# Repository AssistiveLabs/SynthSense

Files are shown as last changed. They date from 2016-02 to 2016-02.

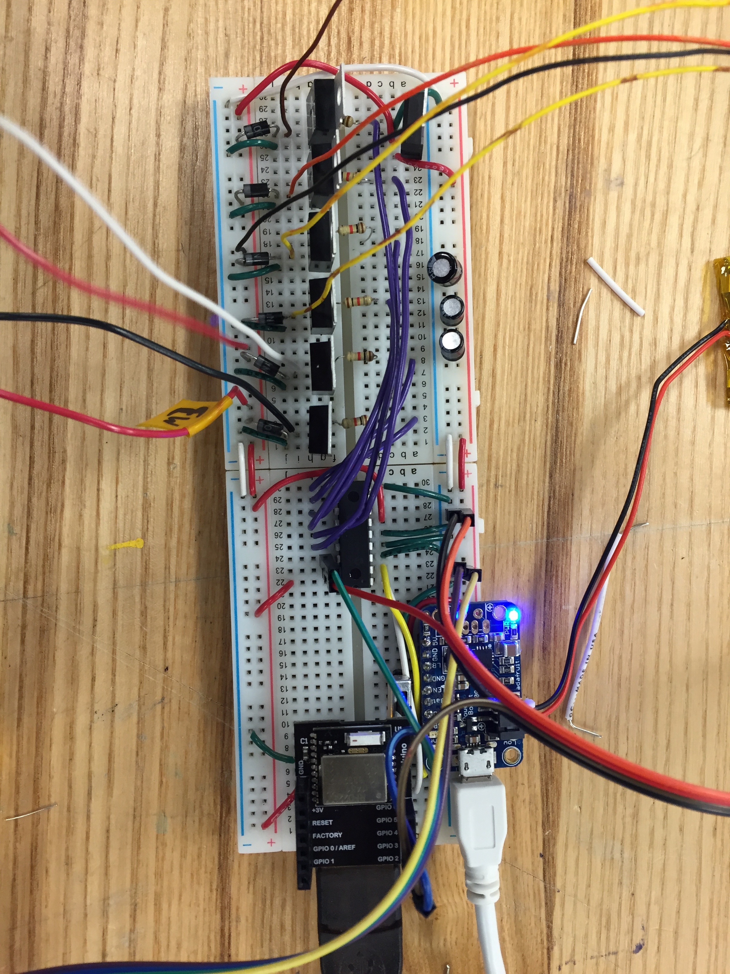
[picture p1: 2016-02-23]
images/Electronics1.jpg

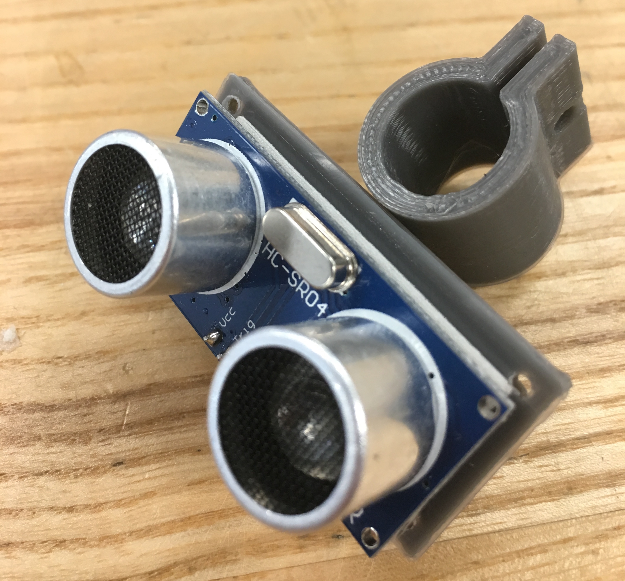
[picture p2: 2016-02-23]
images/Sensor1.JPG

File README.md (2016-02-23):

##SynthSense

####Team
Craig Hiller, Frank Lu, Adithya Murali, Krishna Parashar, Tomás Vega

####Course
Interactive Device Design, fall 2015

Aimed at empowering the visually impaired by augmenting their awareness of the environment and facilitating independence, SynthSense is an open-source Augmented White Cane (AWC) that provides both obstacle avoidance and navigation assistance.

To help with obstacle avoidance, the team built a cane with ultrasonic range finders for detecting obstacles within a two-meter range as well as mounts for the sensors that are both direction- and height-adjustable. Feedback from these sensors deliver haptic responses on the handle when obstacles are detected at body or head level.

To provide navigation instructions to users, the SynthSense team developed an iOS app that determines when the user needs to turn. The app transmits a command to the AWC’s strap, providing directional haptic feedback that the user can act on.

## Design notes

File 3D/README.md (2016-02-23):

# CAD-files
3D models for enclosures and mounts.

### Handle Enclosure
[A360 Link](http://a360.co/1NjnoRl)
Image of finished enclosure

### Sensor Mount and Enclosure
[A360 Link](http://a360.co/1NjnrN0)
Image of finished sensor mount

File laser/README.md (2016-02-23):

# SynthSense Laser Files
The files in this repo are what we used to create the HC-SR04 (ultrasonic ranger) enclosures out of acrylic and the navigation wrist band, which was made out of leather.

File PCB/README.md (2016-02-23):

#SynthSense PCB

---

###Components
- [RFduino](http://www.rfduino.com/wp-content/uploads/2015/08/RFD22301.Data.Sheet.08.20.15_4.36PM.pdf)
- [IO Extender (MCP32008)](http://ww1.microchip.com/downloads/en/DeviceDoc/21919e.pdf)
- [SparkFun Power Cell - LiPo Charger/Booster](https://www.sparkfun.com/products/11231)

###Inputs
- [2x Ultrasonic Range Finder (HC-SR04)](http://www.amazon.com/SainSmart-HC-SR04-Ranging-Detector-Distance/dp/B004U8TOE6)

###Outputs
- [6x 12mm x 3.4mm coin motor](http://www.amazon.com/Voltage-Vibration-Micro-Motor-Phone/dp/B00NP4ARF6/)
  - Voltage: 1.5v-3v
  - Continuous Current: 55mA

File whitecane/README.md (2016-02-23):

## SynthSense
### Obstacle Avoidance

Navigating to a completely unfamiliar surrounding is already difficult, it’s also a challenge to avoid obstacles on the way to a destination. The main issues are

#### Sidewalk Crack Detection
  - Cracks are really hard to notice. An uneven road surface can easily trip anyone. Moreover, canes can get stuck in a crack and break. No current cane system we could find detects this. Our alert system will alert the user before such situations occur. 
#### Overhead Obstacles
  - Low hanging tree branches are hard to detect because the normal assistive device only detects ground level objects. Current systems allow for this. We intend to integrate it into our device.
#### Thin objects
  - Objects such as flag poles  and tree trunks are very easy to miss due to how skinny they are.

#### Possible Solutions
- Augment the white cane
- Delivers feedback on objects above ground-level
- Magnetometer + multiple distance sensors (TBD)

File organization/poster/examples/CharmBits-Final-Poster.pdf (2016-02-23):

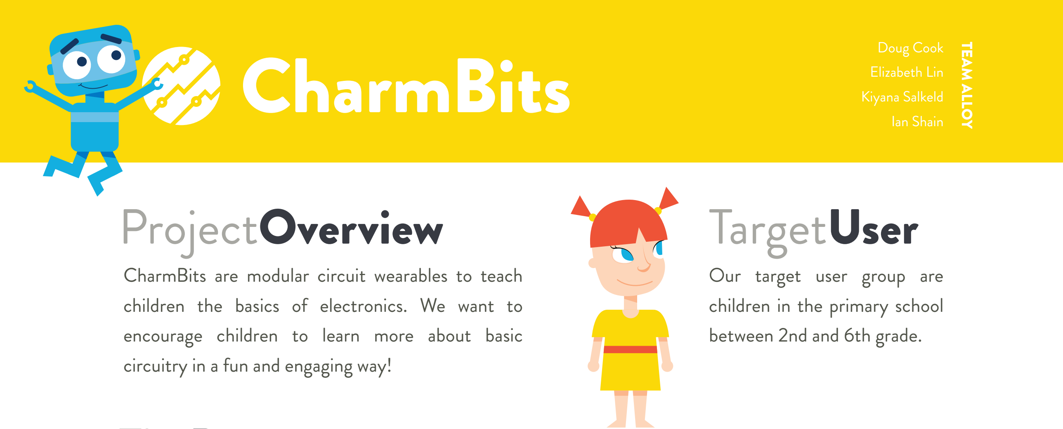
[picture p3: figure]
circuitry in a fun and engaging way!; Our target user group are children in the primary school between 2nd and 6th grade.; Doug Cook Elizabeth Lin Kiyana Salkeld Ian Shain; TEAM ALLOY; ProjectOverview; TargetUser

CharmBits are modular circuit wearables to teach children the basics of electronics. We want to encourage children to learn more about basic

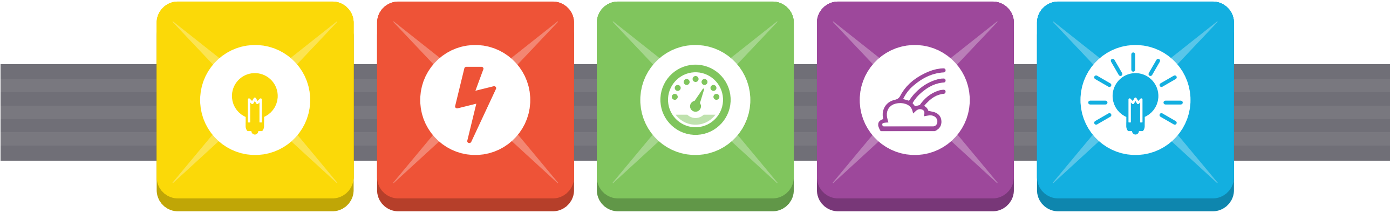
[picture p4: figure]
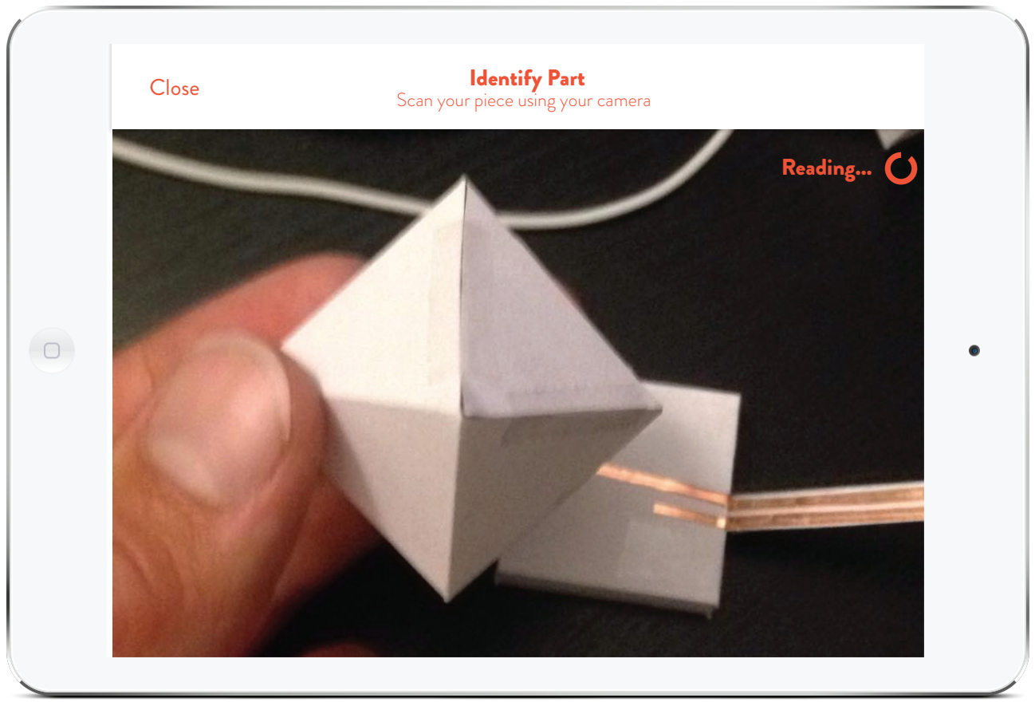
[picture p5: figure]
Close; Identify Part; Scan your piece using your camera; Reading...

Parent-Child
Educational

Child-Child
Collaboration

Child
Exploration

# TheBits

LightBit | PowerBit | MotionBit RainbowBit | BlinkBit

# BitAnatomy

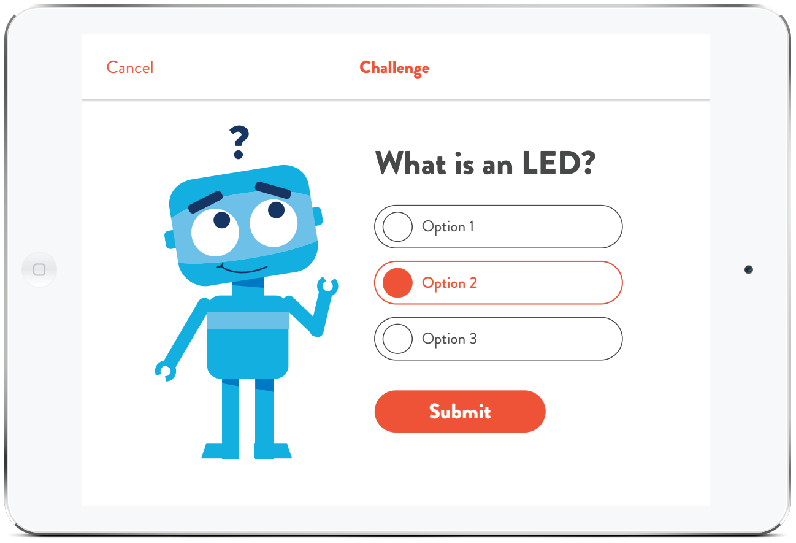
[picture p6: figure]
Cancel; Challenge; What is an LED?; Option 1; Option 2; Option 3; Submit

# UseCases

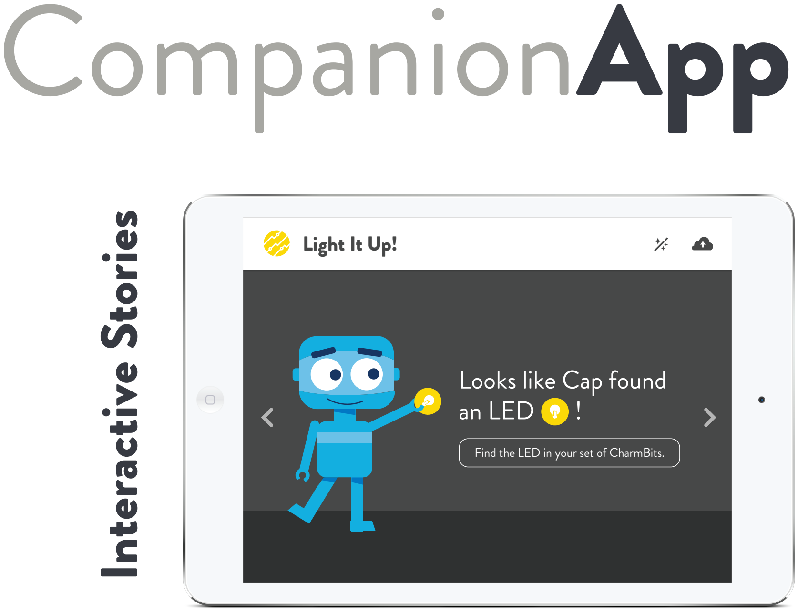
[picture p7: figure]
Light It Up!; Looks like Cap found an LED !; Find the LED in your set of CharmBits.; CompanionApp Interactive Stories

Assessment

Part Identifcation

Every Charmbit is powered by the same internal PCB design and micro controller. Each contains one LED, the microchip, and possibly a sensor if the charm bit requires it

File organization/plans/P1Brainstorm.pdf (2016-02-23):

# SynthSense

## Team

- Adithya Murali
- Craig Hiller
- Frank Lu
- Tomás Vega
- Krishna Parashar

## Ideas

1) Autiteach: Emotion translator for kids with Autism. Use Machine Vision to recognize facial expressions and superimpose description of emotion on real-time video on phone/tablet. Although autistic people are not able to inherently understand emotions, they can still learn to recognize what each means and how to respond to them.
2) MuscleIOT: Control the environment around you with remaining muscle control for paraplegics.
3) Pseudo-Mechanical Bots that overlay on existing controls, and trigger input devices in your home (light switches, curtains, outlets).
4) HighLife: Wearable camera that is triggered at predetermined times/high heart rates to capture peak moments of your life(for example, in dangerous situations/ for old people with heart conditions).
5) Travis: power plugs that monitors power usage and upload to an online dashboard which user can control power outputs and machine learning can be done on the data to minimize daily power consumption
6) Trashbot: smart trash cans that sorts and recycle garbage so you need multiple trash cans for different kind of trash.

7) Meditaid: Haptic feedback to aid in breathing control for meditation practice. The faster the heart rate & breathing rate, the higher the pulsing frequency. As the user enters the meditative state, the frequency and strength of vibrations is reduced.
8) Lucifer: haptic lucid dreaming tapper that taps your palm throughout the day in a timely manner. When user is in dreaming state, the lack of feedback provides a gateway to recognizing they are lucid dreaming.
9) Katara: Shower heads/ sink add-ons that track water temperature and water usage. Automatically adjusts water temperature and notify you when you use too much water.
10) Navi: A navigation dashboard with HUD display that integrates hand gestures and voice inputs(e.g. share your location with your friends without calling them or texting them while driving) that allows the for a safer driving experience.
11) VirtualKeyboard: Using Oculus VR and leapmotion/3Dcamera, we can project a keyboard on any surface and do some simple pose-tracking of fingers to simulate a keyboard to write onto an offline machine
12) ShotTime: A motion based timer for tracking curling shot time, to accurately gauge where a rock will end up or how much sweeping is required. It can report the times and motion data to an app that you could review at a later time to help improve your game.
13) Breathless: An adjustable sized container lid that when activated, will remove all air from a container (via vacuum) to keep food fresh for longer periods of time.
14) ScrewedUp: A remote controlled robotic screwdriver that can get into awkwardly tight/hard to reach places, controlled by iPhone to allow simple fixes that were otherwise difficult.
15)Auto[Computer]Desk: Augment a standard desk so that it can rotate to avoid bright light coming from the sun to avoid glare and unnecessary strain on someone’s eyes.

16) Self Moving Furniture: Computer controlled motors that wheel furniture around, allowing you to rearrange a room, without any effort, with a tablet. Perfect for a classroom setting where the teacher has to assign project groups or arrange a seating change.
17) Kitchen Augmentation: A device that can be used with multiple kitchen appliances to provide useful information to someone while they are cooking. It could include a scale in a heat-resistant package and a screen that can show recipes, and tell you when you have added enough of an ingredient, according to the recipe.

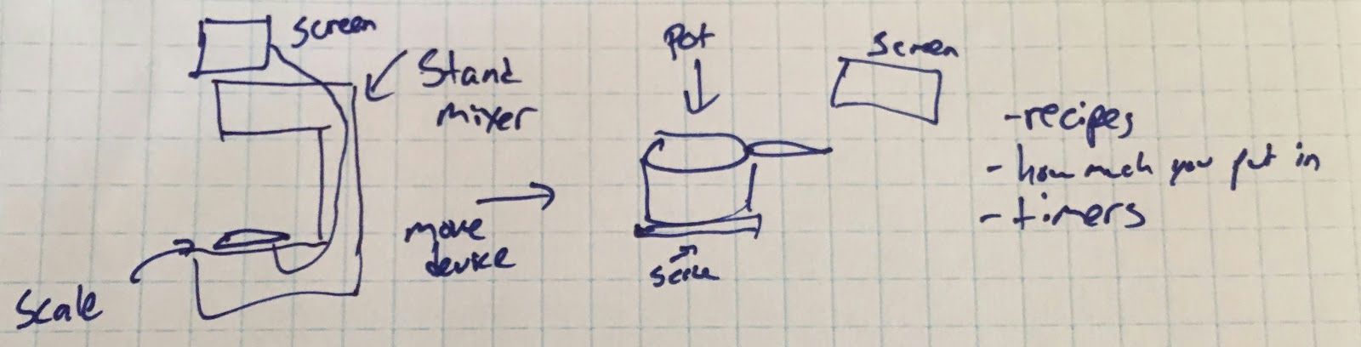
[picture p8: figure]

18) PillPauper: A container that holds medicine, daily supplements and dispense appropriate amount of medication configured by health professionals.
19) Light measurement - [related to research] combines IR and visible spectrum cameras, with a spectrometer, light meter, and IMU in an integrated package that is able to determine how much energy a given light fixture is consuming.
20) SynthSense (described in more detail later)

## Idea Selection

We chose to develop SynthSense because it has the potential to have a very meaningful impact in the lives of the visually impaired. Moreover, human augmentation is a fascinating field. We want to push the limits of our neuroplasticity. Finally, our skillset gives us a high probability of success on this particular project. We have experience on machine vision, software engineering for scientific computing, HCI, cognitive neuroscience, embedded systems, and rapid prototyping.

## Project Description

Target User Group

People with heavy visual impairment and blind people. This target user group usually has a hard time avoiding obstacles without assistive canes/ or guide dogs. Even with the help, blind people can still run into objects such as low-hanging tree branches or slip on objects such as socks, banana peels, etc. Moreover, they usually have to keep a memory map of the surroundings. They need an alternate feedback system that provides a more direct, comprehensive, on-the-go information about the surroundings. This system can be used to reassure blind people when they navigate and try to make sense of the environments.

Problem Description & Context
We’re tackling the problem of navigation for the visually impaired. In situations where there is a lot of extra noise, our target user group can no longer rely on auditory feedback as the only source of obstacle detections. In a crowded place especially, it becomes increasingly difficult to rely on tactile and auditory feedback. Related and complementary solutions such as white canes or guide dogs do exists. Although they alleviate the problem, they do not give a direct feedback to the user and also have respective shortcomings. Using a white cane can only detect things on the ground level and it’s inconvenient to bring a guide dog around everywhere.

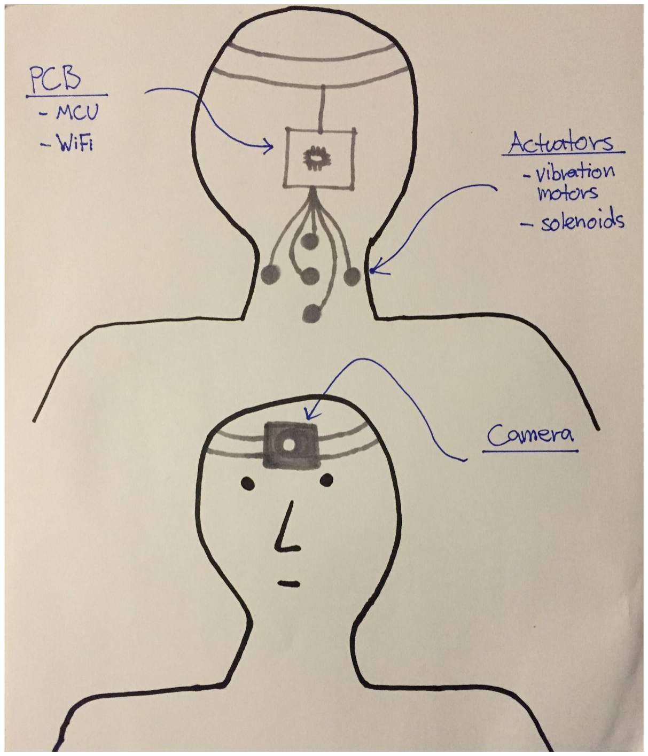
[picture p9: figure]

Why an Interactive Device?
We want to translate visual feedback from cameras to tactile feedback for the visually impaired. We can redirect their sense by utilizing cross-modal neuroplasticity. That is, replacing their visual stream of spatial information with the sense of touch. We can achieve this by having a depth-camera that runs visual processing to locate obstacles and alerts the blind user by tapping the corresponding directions on his or her neck. An interactive device is a good solution for this problem because our target user group naturally lacks the much needed interaction to make sense of their surroundings. An interactive device will deliver a direct and much more efficient feedback to the user, making them more self-reliant when it comes to walking around.

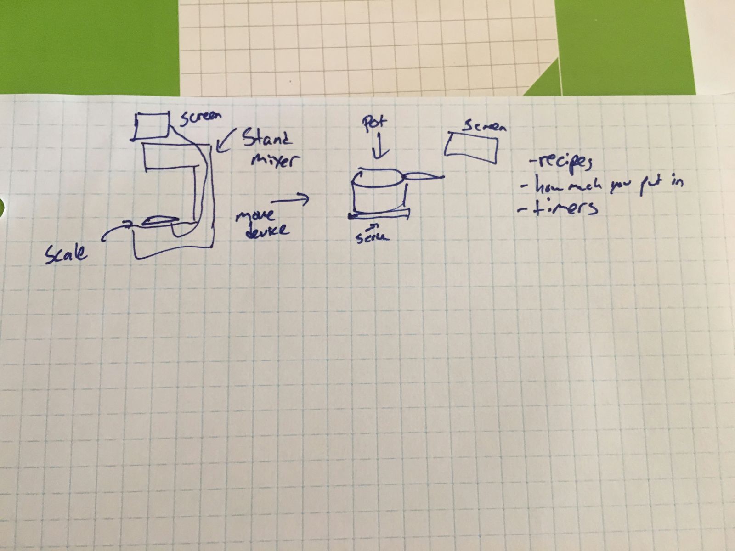
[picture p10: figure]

Open Technical Questions

The current idea we have for the implementing SynthSense involves a depth camera and actuators placed around a user’s neck. We need to see if it is possible to get a depth camera that works with an embedded platform, or if not if we need to implement one ourselves using stereo cameras. Again, we need to see if we have enough computing power to do this.

Tactile Plasticity

- What areas of the body have demonstrated the most potential for increasing their tactile acuity? How much can they change?
- Have some areas shown to have higher neuroplasticity rate? For these areas, which one is the most sensitive?
- Finally, has the precision of the devices tested so far exceeded the precision of the sensory area? The big picture question we are trying to answer is whether the bottleneck is at the hardware, or at the sensory acuity of the body itself.

Feedback Delivery

- How much information can we provide without reaching cognitive overload?
- What is the optimal actuation system to provide clear feedback while maintaining comfort for the user?
- Can we find actuators that are cheap/fast/strong enough to give a user sufficient input about the scene?

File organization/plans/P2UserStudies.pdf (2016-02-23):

# SynthSense

## Team

### - Adithya Murali - Craig Hiller - Frank Lu - Tomás Vega - Krishna Parashar

## Users

Given the time constraints for this project, we selected particular people who we were acquainted with (two students on campus, and one man outside of campus).

### User 1

➔ Senior student at Berkeley. He’s completely blind and prefers using a white cane.
➔ More so than obstacle avoidance, navigation was an important feature he was looking for in new assistive devices

### User 2

➔ Has extreme myopia, unable to see functionally past a few inches.
➔ Navigates without walking cane, but with caution.
➔ Doesn’t travel to new places often
➔ Primarily uses a mobile phone and a monocle to see and navigate.

### User 3

➔ Has cerebral palsy, is locked in a wheelchair, and is legally blind.
➔ He is able to navigate around familiar environments alone, but depends on a caretaker for navigating through unfamiliar places.
➔ He has trouble avoiding obstacles above ground level, curves, trash cans, getting through door openings, and moving on ramps.
➔ When using public transportation, he has trouble locating his wheelchair as he has no sense of what is behind him.

## Process

We attempted to conduct our interviews in an minimally obtrusive environment that was selected and prefered by our users. Thus we interviewed in a cafe (User #1), the user’s home (User #2), and a classroom (User #3). We asked questions focused on challenges in navigation (getting from place to place), obstacle avoidance and explored questions based upon their problems. In addition we asked what assistive devices they already used and what type of device and/or features they wanted most. Overall, all three interviewees mentioned that navigation is an important feature they wanted apart from obstacle avoidance (which we were primarily focusing on in our initial designs).

## Interviews

### Interview 1

User #1 was completely blind and extensively used a white cane. We were really surprised at his keen listening and auditory skills. The interview was held at a cafe but we also walked with him for a while and observed how to dealt with obstacle avoidance on a busy Friday afternoon rush on campus.

The acknowledged that as a student he
doesn’t face too much navigation difficulties.
Nonetheless, whenever he needs to travel and
use public transportation, he’d use Google Maps to plan every detail of his trip and any device that provides locational feedback (or landmarks and directions) would be beneficial. As a completely blind user, some of the common obstacles he faces are low-hanging branches, cracks in the pavement (once he mentioned his cane broke when he
twisted against the crack), crossing the street,
etc.

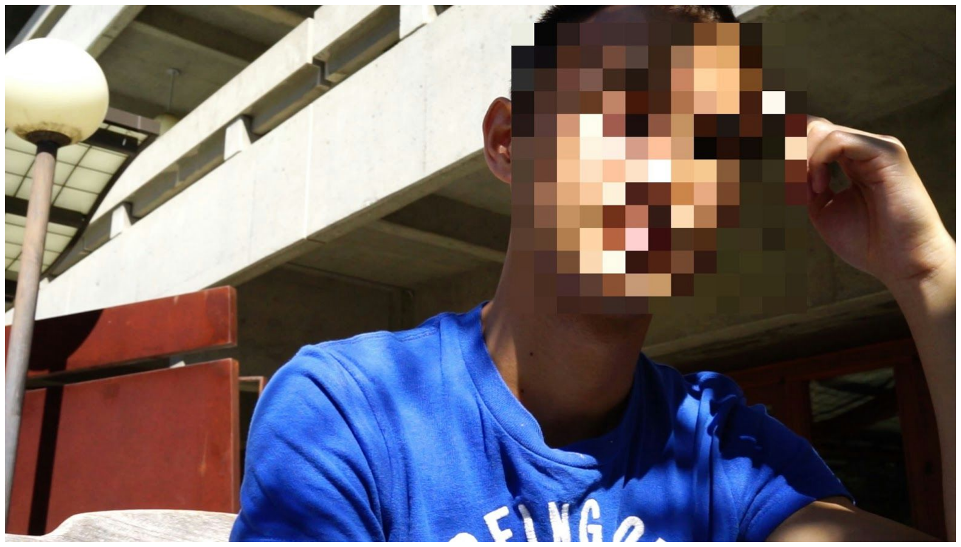
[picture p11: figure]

He emphasized on creating a device that built upon/added features to well-established assistive devices like the white cane. Furthermore, he mentioned an established convention in the field - where the length of the cane should be proportional to the height of the user. This means the cane gives around two-meters lookahead and he would prefer the system to give a minimum of three-meters of information.

### Interview 2

This interviewee was legally blind, with very limited vision at close proximity, and thus was able to provide a unique level of feedback, having a balance between experience with ability and disability. The interviewee is trained to use all manners of assistive devices, but is not absolutely reliant on them, unlike User 1. Primarily, the interviewee’s challenges involved traveling in a new place (this is rarely done as a consequence), which would involve intensive planning of routes using Google Maps and the use of a assistive person and a turn by turn navigation system on a phone. Since his vision is somewhat operable at small distances, a hand held assistive device the accentuates contrasts and feature edges is used, as well as a cell phone camera. Public transportation was easy to navigate, given then local systems use extensive audio systems to allow disabled people to use them.

He often ran into small and thin objects, such as poles, lamp post, and tree branches, especially things that are not prominent or colourful. At home, cord and cables were especially dangerous, and night time walking was difficult. His dream device would be a wrist based obstacle avoidance system that would provide unobtrusive tactile feedback (Especially directional), and that was fashionable. Since primary sensory feedback relies on audio, any device that impeded with that (and/or headphones) were unwanted. He suggested a multimode device that could be activated when needed, and deactivated at other times, stating that he would only need a supplementary device to alert him when things were notgoing normally.

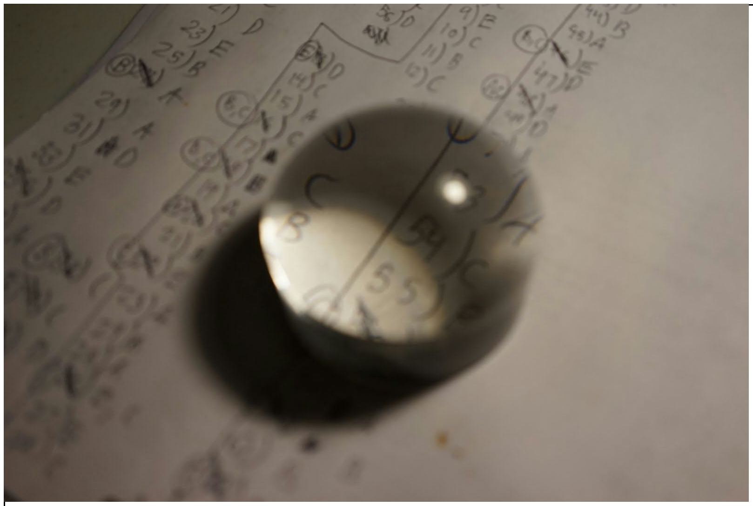
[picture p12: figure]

Magnifier for seeing written text better

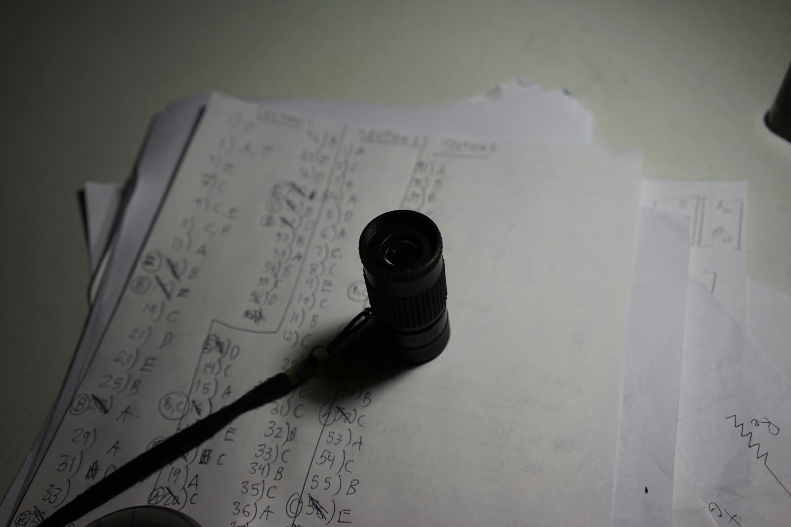
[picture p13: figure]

Monocular for seeing in lectures

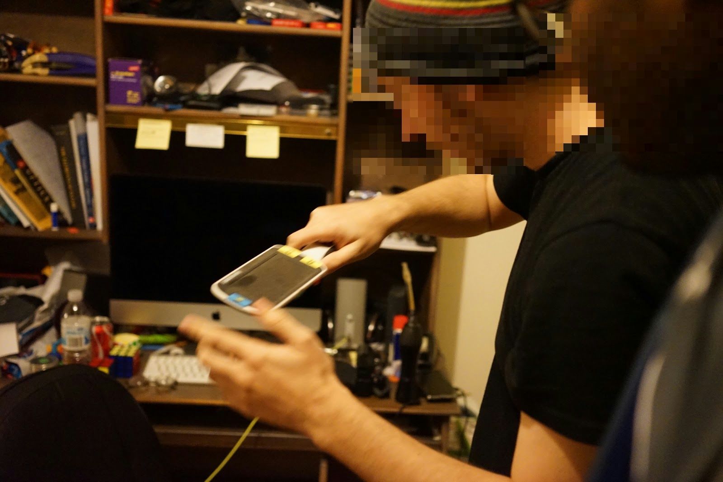
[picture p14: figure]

A camera based magnifier for making objects at various distances larger. It can also adjust color/contrast

### Interview 3

This interviewee has cerebral palsy, is locked in a wheelchair, and is legally blind. Since this interview subject came up from Los Gatos so that we could talk to him, we met in a quiet conference room in Cory Hall. This location was also somewhat similar to normal room in a university, where the subject spends a lot of time. This room also provided a large floor area for him to move in his wheelchair to demonstrate actions. We wanted to minimize other noise and be in as comfortable of an environment as possible. This subject was able to see that there was a blue wall in the room, as well as five people. This interview showed us a whole different set of problems that people can face. In this user’s commute, he is dropped off by an assistive service and has an aid with him. For familiar locations such as his college campus, he knows and can navigate the halls

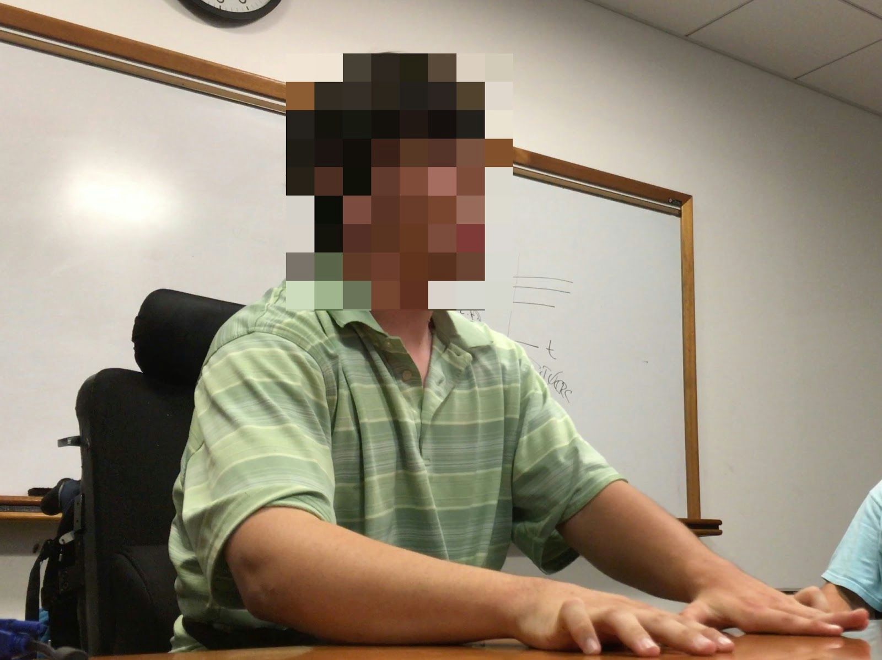
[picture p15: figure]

and between buildings without too much difficulty. However objects that can move such as trash cans or denote boundaries such as walls or door frames can be difficult to avoid.

Unlike the prior users, this subject does not use any of assistive devices due to his situation. Although he was unable to comment on devices that are currently available, he did say that a device that could help him navigate and provide auditory or haptic feedback would be immensely useful. Alerts for objects within about 5 feet would be the most relevant, and would allow him to not run into pillars, walls, or people.

Additionally, the user utilizes public transportation but finds that there is a lot of noise from people, cars, the bus itself which could inhibit an audio signal being used for communicating information. On the note of public transportation, he said it is difficult to tell when he is backing into someone with his chair. He demonstrated this with his brother standing behind him, and running into him. It would be nice, he said, if this wouldn’t have to be a problem.

When asked if there was a device that he wished would exist to help him, he wanted something with GPS to help him navigate and provide instructions on when and how much to turn and that would help him avoid obstacles. We tapped in a linear fashion on his body showing our current idea of how this could be implemented, and he thought it would be useful.

## Problem

People with visual impairment have a hard time sensing their environment. They have difficulty with both obstacle avoidance and navigation. For obstacle avoidance, the most common assistive device is the white cane. This provides them with feedback of the ground plane in front of them by swiping the cane in a parabolic motion. However, this solution doesn’t prevent running into obstacles above ground-level, such as low-hanging branches or even being careful when walking on uneven/bumpy surfaces. For navigation, they rely on mental maps and the help of strangers on the street. However, this is not always reliable and asking for help is not a solution that fosters their independence.

## Solution

We first wanted to concentrate on tackling obstacle avoidance only. After the user interviews, we realized navigation is a vital part for them when interacting with the environment. Thus we determined a two part system would work best - augmenting a cane with obstacle detection and wrist wearables for navigation.

- Obstacle Avoidance
- Augment the white cane
- Delivers feedback on objects above ground-level
- Magnetometer + multiple distance sensors (TBD)
- Navigation
- Wristband that signals next direction to take
- Array of vibration motors

## Key Tasks

### 1. Navigation

It’s usually a hassle for blind people to get from point A to point B. They have to plan out the routes ahead of time and utilize public transportation, which are sometimes not well-designed for the visually impaired. Other times, they have to use a distracting hand held GPS/ Moreover, lack of “checkpoints” and landmarks makes it hard to navigate and gauge how far they are away from the destination. Our wrist based, non intrusive system will allow for a hands free and comforting journey.

### 2. Obstacle Avoidance

Navigating to a completely unfamiliar surrounding is already difficult, it’s also a challenge to avoid obstacles on the way to a destination.

a. Sidewalk crack detection

Cracks are really hard to notice. An uneven road surface can easily trip anyone. Moreover, canes can get stuck in a crack and break. No current cane system we could find detects this. Our alert system will alert the user before such situations occur.

b. Overhead obstacles

Low hanging tree branches are hard to detect because the normal assistive device only detects ground level objects. Current systems allow for this. We intend to integrate it into our device.

c. Thin objects

Objects such as flag poles and tree trunks are very easy to miss due to how skinny they are.

## Storyboard

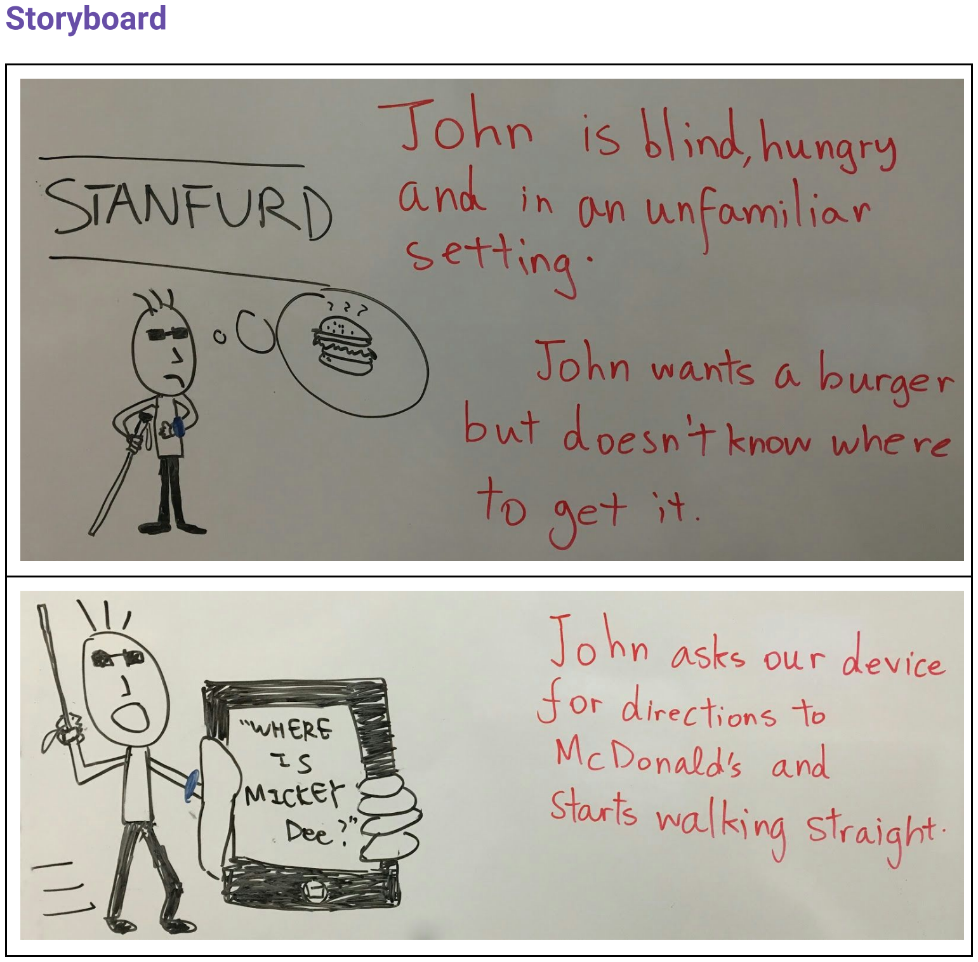
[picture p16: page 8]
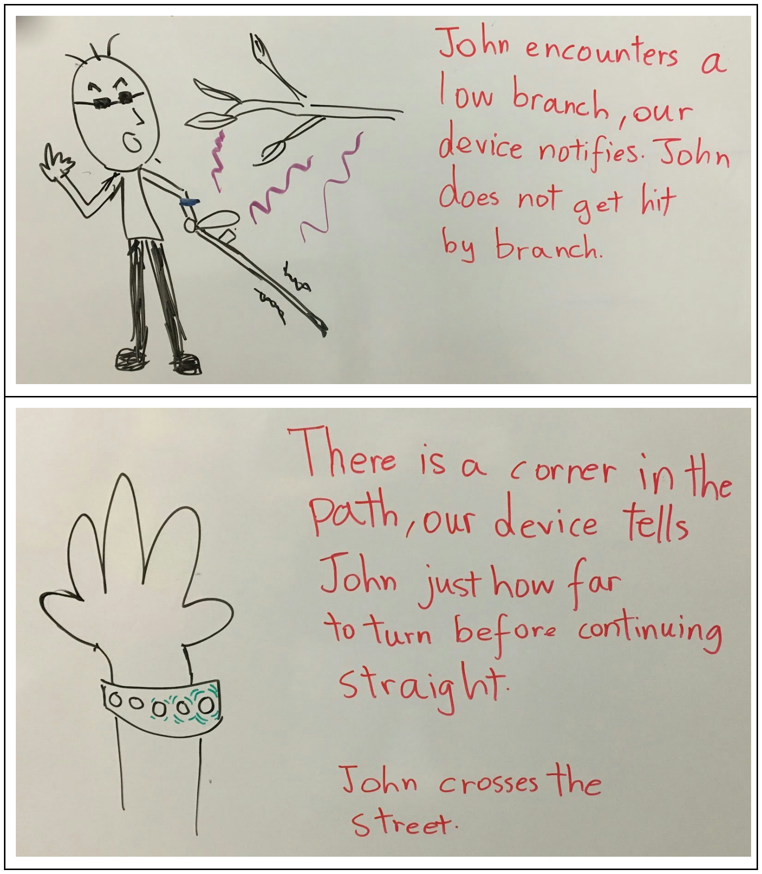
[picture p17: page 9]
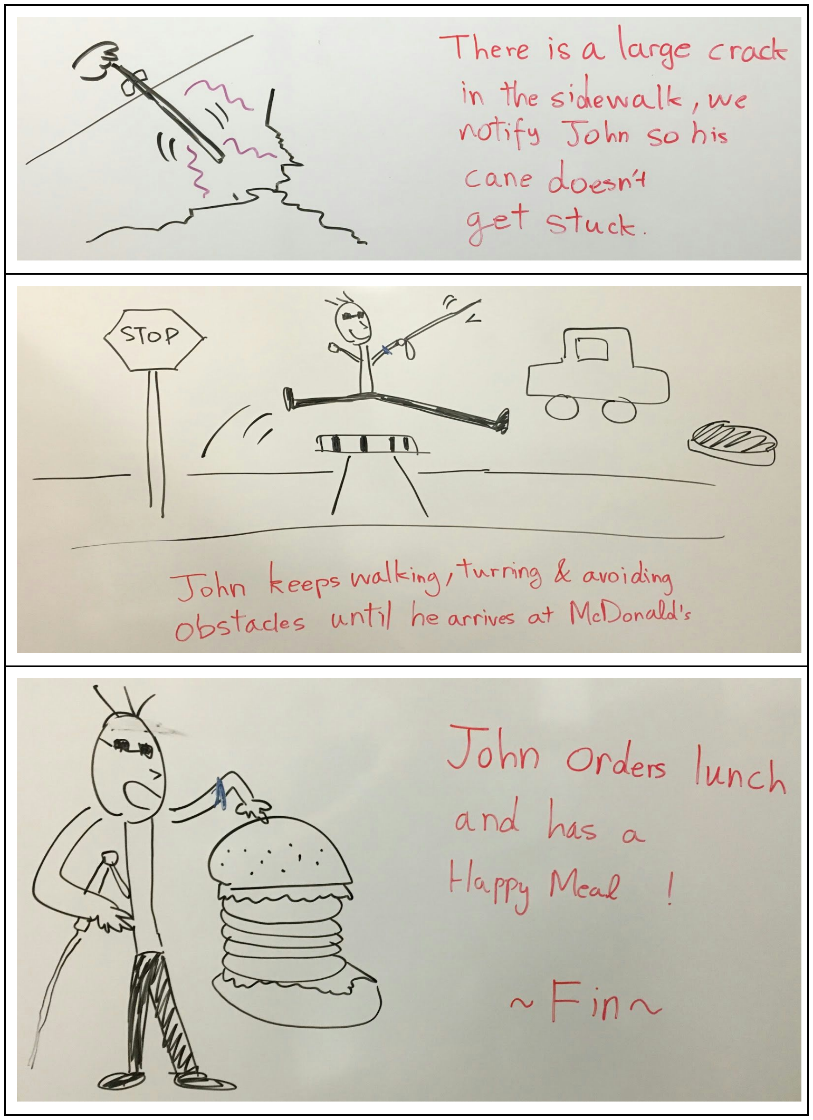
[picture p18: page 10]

## Competition

## 1 |Buzzclip

https://www.indiegogo.com/projects/the-buzzclip-wearable-ultrasound-for-the-blind#/

Target User Group:

The market for Buzzclip is blind people, as it provides tactile obstacle detection. We have the same primary market as them, although a target market for Buzzclip very low cost solution is the third world, which we don’t necessarily have the capacity for.

Usability:

Buzzclip is still undergoing their funding, and is widely untested; Early users are happy with not running into things.

Functionality:

Buzzclips allows users to avoid obstacles outside the range of a cane, we will implement similar technology in an existing advice (the cane), as well as augment the system with a bracelet based navigation.

## 2 |Sunu

http://sunu.io

The mission of Sunu is to empower the visually impaired by improving their awareness of their environment.

Target User Group:

They are targeting the same user group as us.

Usability:

Sunu has been collaborating with the visually impaired in order to create something that really solves the problem. However, it seems that the user needs to rotate their wrist in non-natural ways in order to point the ultrasound range finder. Our solution will improve in the comfort of use in order to provide a more natural and intuitive way of pointing and receiving information.

Functionality:

The application provides three functionalities. The main one is proximity sensing to prevent running into obstacles, a vibration clock that provides the user with the time, and an object finder using beacons attached to objects. All of this information is delivered via haptic feedback on the wrist. Our implementation wants to prevent feature overload, so we are focusing on obstacle avoidance and navigation.

## 3 |Miniguide US

https://shop.aph.org/webapp/wcs/stores/servlet/Product_Miniguide%20US_1189771P_10001_11051

Augment information from other mobility aids, like the cane or dog guide,with obstacle detection by the Miniguide from 1.5 to 26 feet.

Target User Group:

Miniguide’s target user group is the same as our target user group with a primary focus on blind and deafblind persons.

Usability:

The Miniguide US can only used along with a human guide, dog guide, or cane because it does not detect drop-offs and does not provide sufficient information to ensure safety. Our proposed idea of integration of a cane and detective sensors will solve this problem.

Functionality:

It uses ultrasound to detect objects, and gives tactual or auditory feedback by vibrating or chirping more rapidly as you approach an object. Though the device is lightweight and easy to carry around, our idea ofintegrating with a cane and a bracelet to provide full navigation abilities.

## 4 |Trekker

http://store.humanware.com/hus/trekker-breeze-plus-handheld-talking-gps.html

Target User Group

The target audience is the same as ours, the visually-impaired.

Usability

Given a destination that a user would like to go to, the device gives information on an user’s location based on GPS and directions he should take. It also verbally announces when important landmarks (a street, crossing) is reached and connects to GPS within 10 seconds.

Functionality:

Our device strives to achieve the same goal. Nonetheless, when we discussed with the interviewers they all preferred a navigation system that gave haptic feedback on the wrist (as a wearable device). While Trekker provides audio feedback and instructions, the interviewees mentioned that they would rather be listening to music on their headphones or would faced noisy environments where it would be hard to hear.

## 5 |Advanced Augmented White Cane with Obstacle Height and Distance Feedback

http://ieeexplore.ieee.org/stamp/stamp.jsp?arnumber=6650358&tag=1

Target User Group The target user group for this paper/solution is blind or visually impaired people who have the ability to walk around on their own, this is the same group of people that we are targeting.

Usability: This competitor appears to have a good user experience for obstacle avoidance although the sensors may have trouble performing in all environments, specifically hallways and sloped roads, we would improve upon this experience by adding additional sensors and software to correct for these situations and add a navigation component to meet more of our user groups’ needs.

Functionality: The main functionality of the device is a way for the user to tell what obstacles are in their path at different levels, our proposed idea will extend this by providing a way to receive navigation instructions, which was one of the main requests from our interviewees.

## Competition Summary

The competition is focused on augmenting existing solution or providing auxiliary products, that either solve
A) Obstacle Avoidance or B) Navigation, but not both. We intend provide a modular system of devices that will augment the widely used cane, as well as provide haptic feedback for a turn by turn navigation system, that will provide on demand and unobtrusive guidance.

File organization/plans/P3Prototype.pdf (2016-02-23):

# SynthSense

## Team

- Craig Hiller
- Adithya Murali
- Frank Lu
- Tomás Vega
- Krishna Parashar

## Questions and What We Learned

1. What is the most effective way to detect dropoff?
- The two ways we were considering for detecting dropoff involved using either an IR or an ultrasonic distance sensor. We concluded that the ultrasonic sensor would give a false positive when passing through narrow openings such as doors, but the IR sensor would not have this problem as it has a narrower beam.
2. Can we connect multiple ultrasonic sensors at different angles to detect obstacles at different levels?
- Yes! We had two different ultrasonic sensors and the IR sensor connected and were able to detect the objects at different levels. Part of the unknown that we addressed here was how to mount the sensors, which we solved. The solution is shown later in the pictures.
3. Can we get reasonable haptic feedback with the two types of vibration motors?
- Again, yes. We used both small eccentric rotating mass motors and coin vibration motors, and both of them gave us the vibrations we desired, and they can be run off of the IO pins on the various controllers that we have, which was an added benefit.
4. It is possible to have vibration motors give a sense of direction on the wrist?
- To tackle this, we built a very lo-fi prototype of the navigation portion of our project, and had all of the vibration motors go off in sequence, the result was a clockwise rotating feeling around the wrist, as we desired.
5. Can we get directions to a location by speaking into a phone?
- We needed to figure out if there was a usable speech recognition API that we could use on the phone, and if it is possible to use the strings returned from that to get directions from the current location to that place. This turned out to be possible thanks to sample code from Nuance and their SpeechKit.

6. Can we easily power our devices?
- We learned that we need to have a decent power supply for the obstacle avoidance system, on a small battery when we tried to run the motors and sensors, we didn’t have enough power so we experienced some unexpected behavior. This was fixed by using USB for the power, so this is still under investigation.

## Look and Feel Prototypes

For this deadline, we really wanted to tackle the technical challenges that were ahead of us. But we also wanted to think more about the “ideal” product should look like, independent of if we could build it at the current time. This is what our current thoughts for the best version of this project look like:

### Obstacle Avoidance

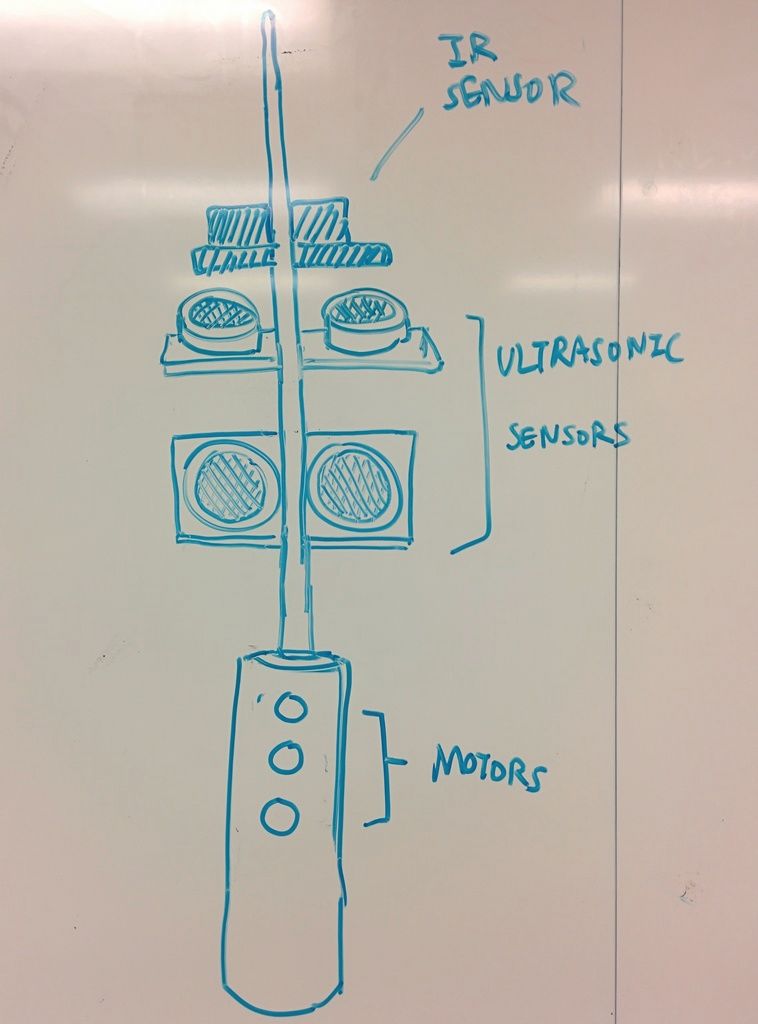
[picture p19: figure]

We wanted a design that separated the sensors from the handle to avoid having the user accidently block them. This then has all of the haptic feedback motors in their own ergonomic enclosure, so that is all the user has to concern . This image is very much not drawn to scale, the cane is much longer than any of the devices we are adding.

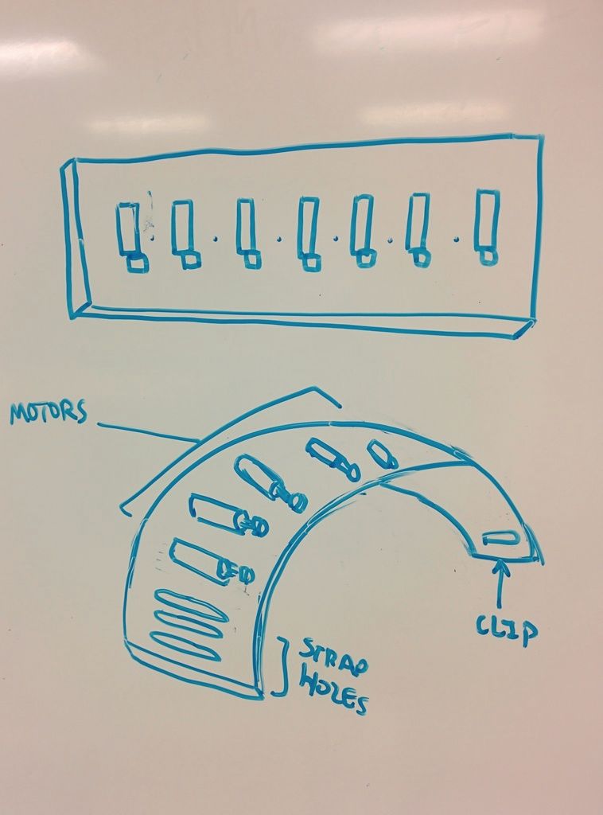
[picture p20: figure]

### Navigation

The navigation bracelet is the part of the project that is worn on the user to provide feedback about which way to turn/walk to reach a destination. We want it to be controlled through bluetooth to a phone that provides the turn-by-turn instructions. On the bracelet itself, we wanted a minimalistic design, with only the motors and a clasp visible. In future versions, we want to hide the motors so they don’t get caught in anything, but we haven’t figured out a tradeoff between how this is constructed and how it would look. The clasp we’re thinking should be a standard watch-type strap with a pin and holes or a magnetic enclosure. Further testing is required to settle on a design on that front.

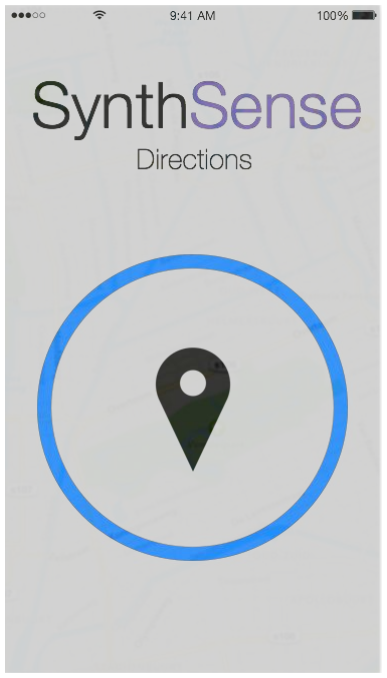
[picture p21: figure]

### Controlling App

To create a “look-and-feel” prototype for this app, we had to consider who our use base is. Namely, blind people. Since they cannot see, this prototype needs to be very simple to use provide audio feedback instead of visual. While our prototype does have an appealing visual aspect to non-visually impaired people, the main functionality is controlled by tapping anywhere in the middle of the screen. When this happens, the device will say “Say your destination address”. After the user has spoken the address, the speech-recognized version is read back. The user can then confirm if this is correct by saying “Yes” or “No” after being prompted. If the user confirms the address, the app will then send haptic instructions to the navigation wristband for the turn-by-turn directions. The data sent can be augmented by sensor readings from within the phone. A mockup of the main screen of our controlling app is shown to the right.

## Look and Feel Prototypes

The following prototypes are what we were actually able to build! They were built with the focus of tackling our main technical questions, and for the most part were a good platform to do that. These platforms let us test a bunch of different questions we had without having to build a new device for each test, so this prototyping stage was incredibly valuable. We did have our challenges, discussed later. But for now, this is what we built.

### Obstacle Avoidance

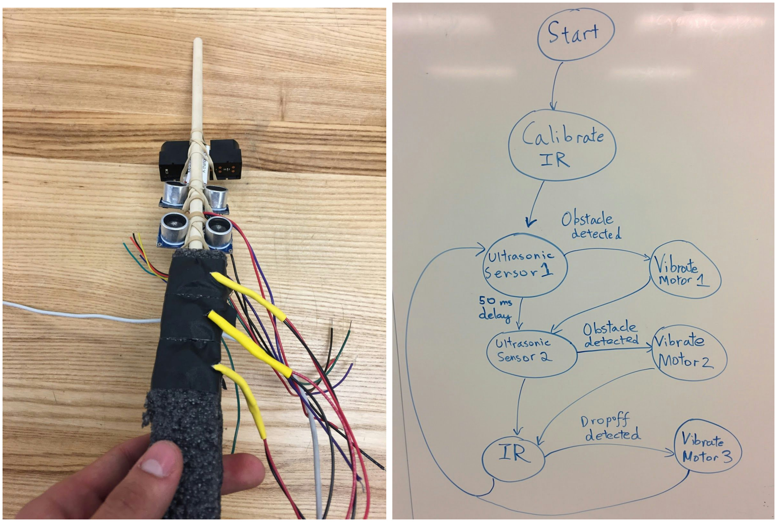
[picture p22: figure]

The augmented white cane prototype is constructed from black foam and a short dowell. We didn’t want to invest significant time/resources into designing a proper handle or buying a white cane. Using these materials, we were able to iterate quickly on what worked and what didn’t, such as positioning the ultrasonic sensors. Since we secured them with rubber bands, they were easy to adjust. To keep the angles, we just had to put an appropriate sized stopped behind them. The dowell fit nicely between the sensors so it was easy to attach. The black foam as a handle provided a decently comfortable solution that was easy to resize/remake. We easily taped the coin vibrators onto here and we could check if the positioning felt good in a human hand. Also pictured is the state machine that powers the measurements/feedback in the cane.

### Navigation

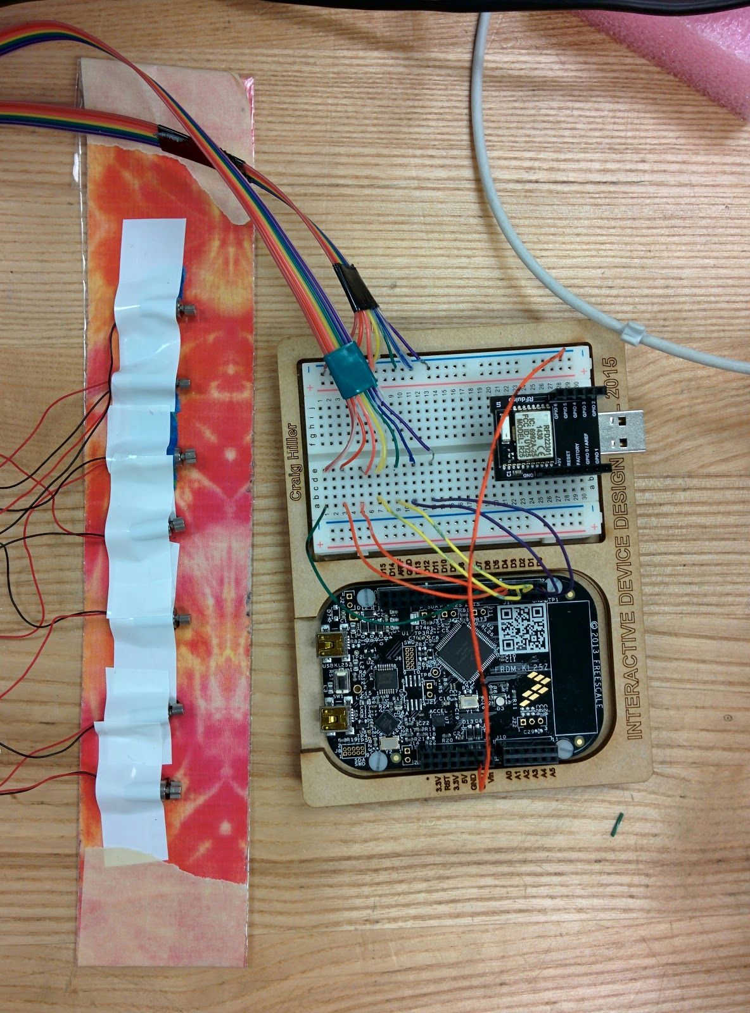
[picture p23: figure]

With this prototype, we really wanted to see if the motors could be controlled from a microcontroller and if by doing so we could get a decent sense of motion on the wrist. To start this, we first needed to make a wristband. Since we wanted something quickly, this is made from a couple strips of duct tape covered in packing tape. Instead of a complicated clasp mechanism, a piece of masking tape (the white tape on the ends of the band in the picture) was used. Next, we obviously needed the motors, we decided to put on seven since it allows for three on each side of the wrist and one in the center, which may be useful later. These were taped on in roughly equal spacing across the band, leaving extra room at the ends to allow the band to close. This current version has a mess of wires, but in future versions we hope to clean this up and keep it more self-contained. It would be useful to add H-bridges to this circuit as well so that we can reverse the direction of the motors. This would improve the resolution of the vibrational pattern and thus, provide a more distinct sensation. With this prototype we were able to test different numbers of motors, and get a glimpse as to how this system could feel on a user’s wrist. A demo of the band is here: https://youtu.be/f-9pZ1GHJiE

### Controlling App

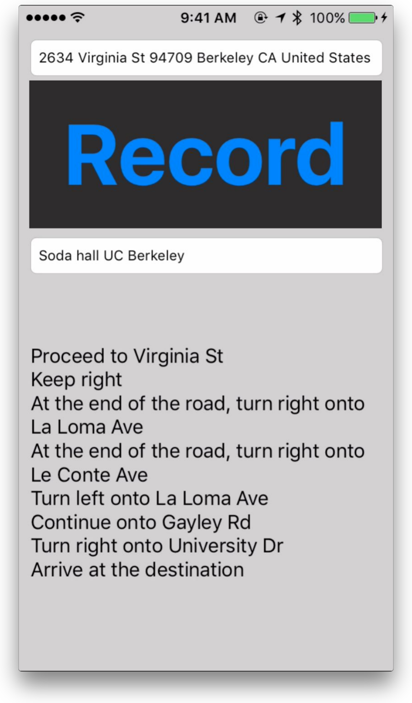
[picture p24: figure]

As a first pass on the controlling app, we modified sample code from Nuance’s SpeechKit. This allowed us to pretty quickly get speech recognition up and running. From there, we determined the user’s current location and then through the geocoder and a directions request determine how to get to the address that the user spoke. The app will repeat the recognized text as voice and directions will be shown on screen. Since this is a prototype for the team, we wanted a quick visual way to see all of this information without dealing with all of the nuances required to be accessible to the visually impaired. Most notably, we don’t have a voice confirmation for the address, and the design is not particularly blind friendly. This prototype did confirm to us that we will be able to get instructions by voice though, which is really what we wanted to address. Here is a short demo: https://youtu.be/0xVNsfzi9LA unfortunatley, the sound generated from the phone was not captured in the recording.

## Challenges

Sensors

- Mapping IR sensor to a linear affine function and measure the bias to calculate correct drop off distance.
- IR sensor is very sensitive to outside light, and we plan on putting a filter, but it might affect the reading.
- We need to ensure that the placement of the IR sensor and how the user uses the cane will allow the sensor to correctly output the readings within the operating range.

Power

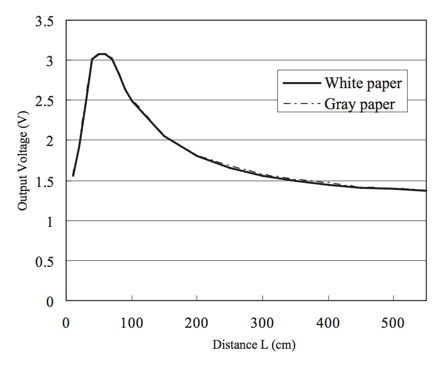
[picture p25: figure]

- Given that our device is somewhat a wearable, we need to figure out how to maximize the battery capacity and form of the device, while minimizing the size to still fit a white cane.
- We’re having issues powering the sensors after attempting to boost up the 3.7V to 5V battery output with a boost converter, so we’re sticking with USB power for now.

Design

- Given the cylindrical nature of the device, we need to design a custom PCB that will fit all the components. Also considering usability, the sensors can be easily broken if exposed. We need to therefore design two enclosures, one for the power components and motors, the other one for the sensors.

Non-blocking Haptic feedback

- Whenever an obstacle is detected, we would like the vibration motor to vibrate (for 3 seconds) but the ultrasound sensor continues to measure readings. Essentially, we could have a separate thread to run the motor. Alternatively, we could start the motor and measure the time stamp. At the beginning of each loop, we verify if the time for the motor vibration has exceeded and turn it off correspondingly.

## Reflection

Overall, we had a pretty successful first prototyping round. We learned a lot from what we built, especially with regards to the feasibility of the whole thing. Some of the highlights of what we learned are: how to provide haptic feedback to the user based off of combined readings from multiple sensors without blocking the processor, that a series of vibrating motors can accurately give a sense of motion and direction, and how to use speech recognition in an iOS app. Basically, we learned the answers to the questions we proposed at the beginning of P3.

Most of the challenges that we faced are listed in the previous section, but one more that arose was team availability and communication. We learned that even if we start early, if we only have a subset of the team working at a time, it is difficult for the others to get back up to speed on the progress that was made. This is something, outside the realm of technical problems, that we will work on improving this week.

One of the main concerns that was brought up from this stage was being able to power everything. We ran into problems with external batteries since they couldn’t supply enough current to power the boards, sensors, and motors at the same time. In the coming weeks, we will need to address these power concerns and figure out a reliable way to power our devices without being connected via USB at all times.

While most of the designs haven’t changed much since we met with the potential users in P2, we became more aware of the nuances of the design. For example, with the navigation band we need to be able to close it in a way that is simple, intuitive enough to be done without visual cues, and secure enough to not fall off while moving throughout the day.

Our designs and implementations still have a fair amount to go before they resemble any sort of non-research useable interactive device. Specifically, we have many different power sources, wires going everywhere, and a slew of different microcontrollers for each part of the project. One of the main things we want to do in the coming weeks is to integrate the three parts of this project together. At the moment each one is separate and not talking each other, which was fine when we wanted to see if everything would work, but now we want to see if everything can work harmoniously. Once we have a link between the three devices, it may be useful to go back to the people we interviewed and get their feedback on the system. By keeping the system modular, we would be able to reuse large parts of the code even if we end up needing to redesign our project.

## Presentation

SynthSense Prototype Presentation (https://docs.google.com/presentation/d/1QJr54sXipRqbXLKb_SM_wXV_WhcaY8cDMvy3FbHNbDk/edit#slide=id.p)

## Code

Obstacle Avoidance :https://github.com/adithyamurali/SynthSense

Navigation band: https://developer.mbed.org/users/chiller/code/NavBandProto/

Controlling App: https://github.com/craighiller/speechDirections

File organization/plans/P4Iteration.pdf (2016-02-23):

# SynthSense

## Team

### - Craig Hiller - Adithya Murali - Frank Lu - Tomás Vega - Krishna Parashar

## User Interface

Given that our target user group consists of blind people, the user interface of our app becomes auditory instead of visual. The user flow thus consists of (1)the user opening the app (currently a native iOS app) using the voice control system built in on to the phone. The app then loads (2)up to a view that has the entire screen as button that (3)when pressed the microphone to allow the user to (4)speak the place they would like to navigate to. The app then calculates a turn by turn navigation to the desired destination, (5)using the navigation band as feedback system that alerts the user to their destination.

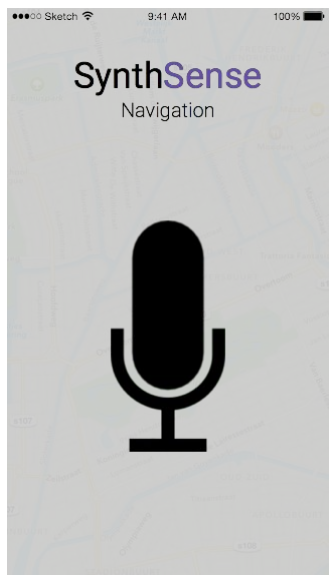
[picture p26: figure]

The screenshots on the previous page are what we would like this to look like in the end. By having information on the screen it allows for non-visually impaired people to look at the screen and see where the user is planning on going if they need assistance. Since we are still on an early prototyping phase, we wanted to focus on the interactions that a blind person has with our application. Specifically, we worked out how to prompt a user for additional vocal input to confirm commands. This could be extended further to allow for deeper navigation through the application. A diagram of the current interactions a user can have with our system is as follows:


Here is a video of this UI in action: https://youtu.be/xAxwXTHDW_s

Since most of the feedback to the user is through the vibration motors in various parts of the project, we also consider that to be a user interface. More details on updates to those to follow.

## BLE Integration

The sensors and obstacle detection feedback systems on the augmented white cane are designed to be completely operable without any wireless data communication, making BLE or WiFi inappropriate for the white cane. However, the navigation band requires a positioning and routing system. It seemed natural to use an iPhone to provide this data to the strap. Since we didn’t want to create a new wifi network for only our devices (since they will be used outside where existing wifi networks may not exist), we went with Bluetooth low energy. We chose an RFDuino for this since it has an adequate number of IO pins, is cheap, and relatively easy to set up with a lot of documentation and sample code available. We integrated this functionality into the app we have been working on by adding a “Left turn” and a “Right turn” button to the bottom of the screen. Since we have not yet determined how we want to approach turn-by-turn navigation, this was the simplest way to test the system. It also means we don’t have to walk in the rain just to see if the motors turn. A screenshot of the app is on the next page. We are expecting multiplexers to arrive this week which should allow us to connect all of our sensors and actuators to a single RFDuino. Because of this we held off on trying to merge the wrist band with the white cane components until we could do a more permanent job.


Video of the left/right turn in action: https://youtu.be/LLXPSRZTLPM

## Code

Augmented White Cane (https://github.com/SynthSense/whitecane)

Tactile Navigation System (https://github.com/SynthSense/navigation)

iPhone Navigation App (https://github.com/SynthSense/app)

Code for RFDuino https://gist.github.com/craighiller/327b23b3422128313613

## Enclosures


### Sensor Casing http://a360.co/1MhXdb1


### Handle http://a360.co/1GTbvlA

For iteration 2 prototyping, we’re trying to make each component modular for the ease of adjusting for user testing and replacing faulty components/ sensors. The sensor casings mount onto the white cane and the handle snaps to to the rear end of the cane while mounting 3 coin motors. Given that the power system and the breakout board of electrical components are still being tested, we decided to leave that out of the handle for now. Our final design will integrate all the components (sensors, MCU, PCB, batteries, motors) into different compartments of the handle.

## Current Prototypes

### Demo Video (https://youtu.be/kL1IcHK98zM)


Sensor Mount | Wrist Strap with Coin Motors

For the wrist strap, we iterated heavily in the past two weeks going through four different models of how it should work before arriving at what is shown above. We began with a simple watch strap, but after attaching some vibration motors to that, we realized it would be the same jumbled mess that we had in the previous iteration. Additionally the strap didn’t close very well, so a lot was left to be desired. We then made a paper look-and-feel prototype with motors and a magnetic enclosure. This (shown below) gave us the confidence in that design to proceed with a fabric version. After many trials with the sewing machines, we decided to stitch it by hand so we wouldn’t keep burning time. For future iterations we are looking into sewing the band on a machine. With this first fabric version, we learned that in order to have the vibration motors not interfere with human skin, we should have them on the inside of the band, with the masses covered so they wouldn’t jam. However, the motors slid forward after the band was stitched shut and all of them jammed. This led us to our final design with coin motors on the interior of the band, these don’t have any externally facing rotating parts and are much thinner which actually made them ideal for this situation. We twisted the cable together to keep all of the wires together and put it on. The magnetic clasp is made from a neodymium magnet on one end and five small strips of metal in the other.


Top row: Paper look-and-feel prototype of the magnetic closure wristband.
Bottom left: ERM motor inside a 3D printed housing to allow it to spin inside the band (worked until the glue slid)
Bottom right: the metal strips that form the other side of the magnetic clasp

We implemented the same state machine we described in P3 for this prototype. Compared to P3 where we powered the microcontroller and electronics (motors, ultrasonic sensor, etc.) with a USB cable, we had the P4 prototype powered by a 3.7V LiPo battery. However, there were several challenges when implementing the powering. We had to use a boost converter for the battery and implement a PI filter for the input voltage. Furthermore, we attempted to house all the electronics on the protoboard for fitting inside the handle enclosure. Unfortunately, there turned out to be some loose connections with the header pins, so we reverted back to the breadboard for the P4 prototype. For the final project, we aim to start early with multiple iterations of the PCB manufacturing process.


Circuit on Breadboard

Circuit on Protoboard


Circuit Diagram on Fritzig

## Work Plan

### Major Steps

Task | People | Description | Estimated Time
Integrate Components | Team | Integrating the Navigation App and hardware and ensure overall functionality. Integrate electrical components and test and ensure there is no abnormal behaviour. | Throughout
iPhone Navigation App | Craig | We have the basics of the app down so far, we can get voice input from the user and get directions. The problem now comes from making this into a navigation app. Starting today, I have a call with Nokia about their mapping APIs, hopefully that will give a good starting point. The rest could just be a lot of code to make this work as we desired. There will be a small UI-prettifying aspect as well towards the later part of this. | 15 Days
PCB Design | Tomas, Krishna, Frank | Design and mill a custom breakout board with Eagle to include surface-mount components and connect the microcontroller. | 6 Days
Enclosure Design | Frank | Refining current enclosure design for the handle to include compartments that house the PCB, battery, and microcontrollers. Adjust sensor mount so that it has a full enclosure around the ultrasonic sensor. | 6 Days
Power Systems | Tomas, Adithya | Source enough power with a boost converter while preventing rippling effect using filters to the cane’s handle to power the ultrasonic sensors and motors. | 6 Days
User Testing | Krishna, Frank, Adithya | Show and discuss prototypes with our users to ensure functionality. Additionally get feedback on improvements to try and implement them. | 4 Days
Project Poster | Adithya, Krishna | Make a poster that showcases the user story, the design process, prototyping iterations, user feedback, as well as the finished product. | 6 Days

Final Assembly | Tomas, Frank | Integration the software and hardware platform and combining power systems, PCB and fit it inside the enclosures and make sure it still works.

6 Days

11/10 | 11/12 | 11/14 | 11/16 | 11/18 | 11/20 | 11/22 | 11/24 | 11/26 | 11/28 | 11/30 | 12/2

iPhone Navigation App

| User Testing
| | PCB Design
| | Enclosure Design
| | | Power Systems
| Integrate Components | | | | Integrate Components
| | | | | | | Final Assembly
| | | | | | | | User Testing
| | | | | | | | Project Poster

Risks to Successful Completion:

- Risk 1: Integration between application software and the two hardware components (both the cane and wrist strap)
- Contingency Plan 1: Combining the cane and wrist strap into one hardware component and use the RFduino and multiplexer and make sure BLE is functioning properly.
- Risk 2: If we are unable to match user’s current location to a position on a route step and track their position along the route as they navigate, we won’t be able to provide turn by turn directions.

- Contingency Plan 2: We could add a button that allows for the user to ask for directions at a given point in space, which circumvents the need to track user position.
- Risk 3: Hardware failure (MCU getting fried, capacitors/ transistors blown, tracing fried on PCB )
- Contingency Plan 3: CAD spare parts, print extra PCB’s, and buy more spare parts. Design the enclosures so that it’s easy to swap out parts and reuse.
- Risk 4: Not being able to fit all the electrical components (power system and micro-controller especially) inside the handle.
- Contingency Plan 4: Create a small enclosure housing for all the electrical components and connect it to the handle.

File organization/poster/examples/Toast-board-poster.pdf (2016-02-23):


▪▪▪▪

▪▪▪▪

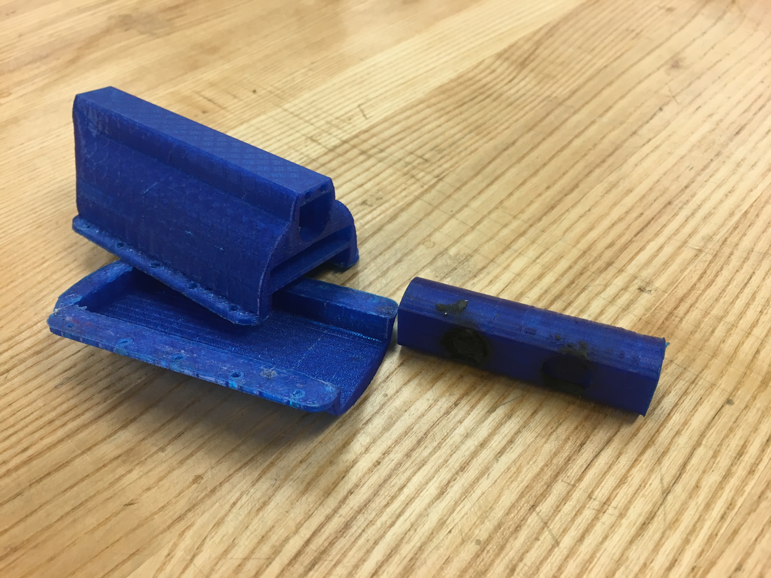
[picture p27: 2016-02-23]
images/Handle2.JPG

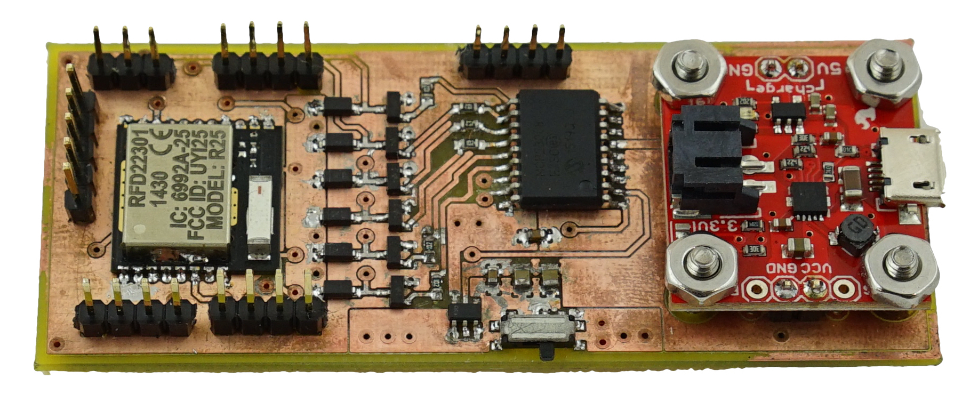
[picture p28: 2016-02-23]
images/PCB_side.jpg

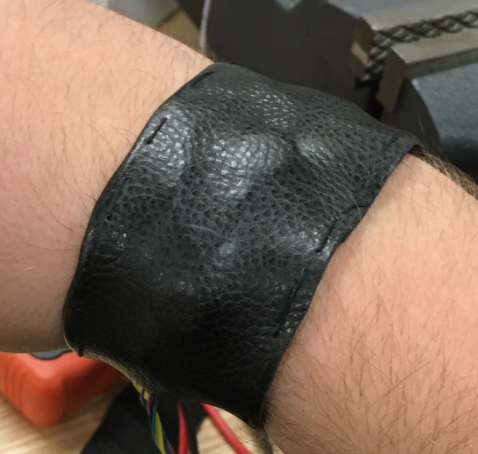
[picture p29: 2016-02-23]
images/Navband3.png

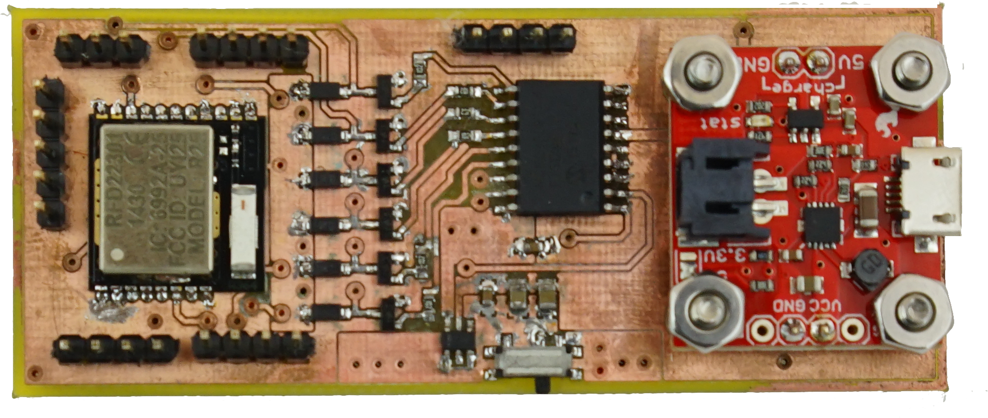
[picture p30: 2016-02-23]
images/PCB_top.jpg

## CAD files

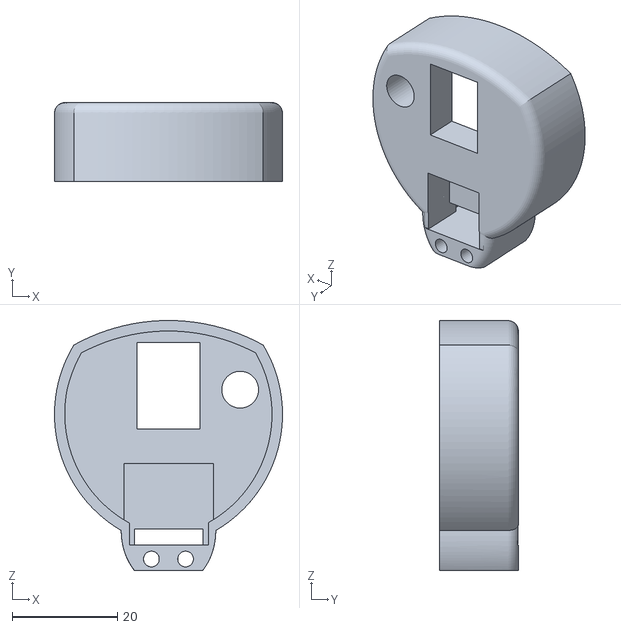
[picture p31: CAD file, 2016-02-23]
3D/enclosure_cap.stl
43.3 x 15.0 x 47.5

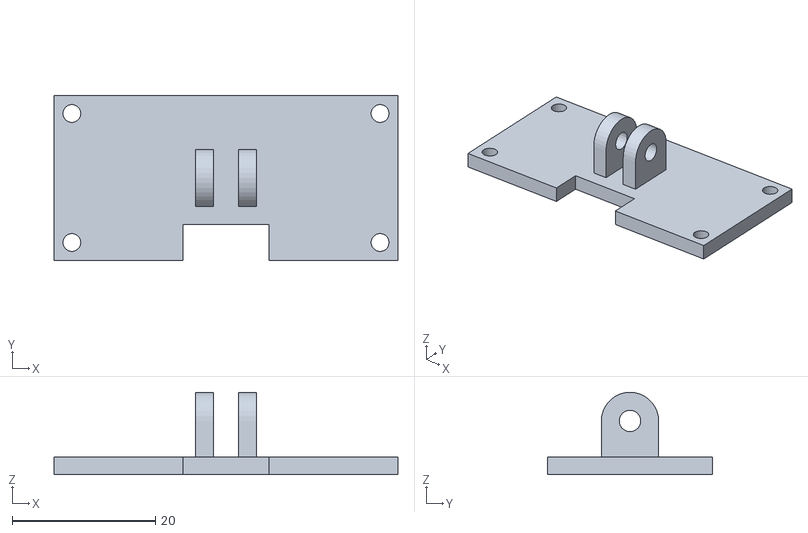
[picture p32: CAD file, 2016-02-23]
3D/sensor_mount_plate.stl
48.0 x 23.0 x 11.5

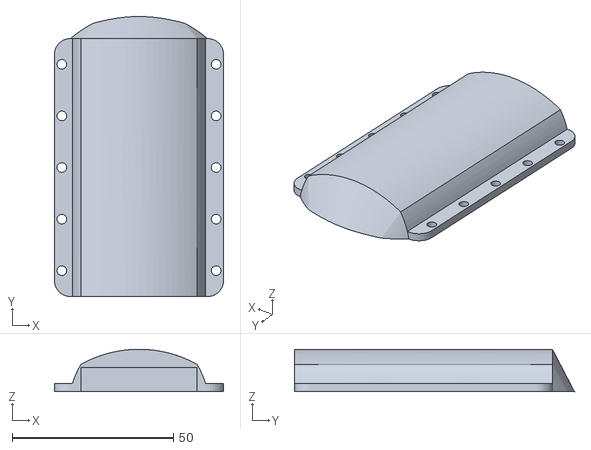
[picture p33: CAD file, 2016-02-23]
3D/enclosure_bottom.stl
52.5 x 86.8 x 13.2

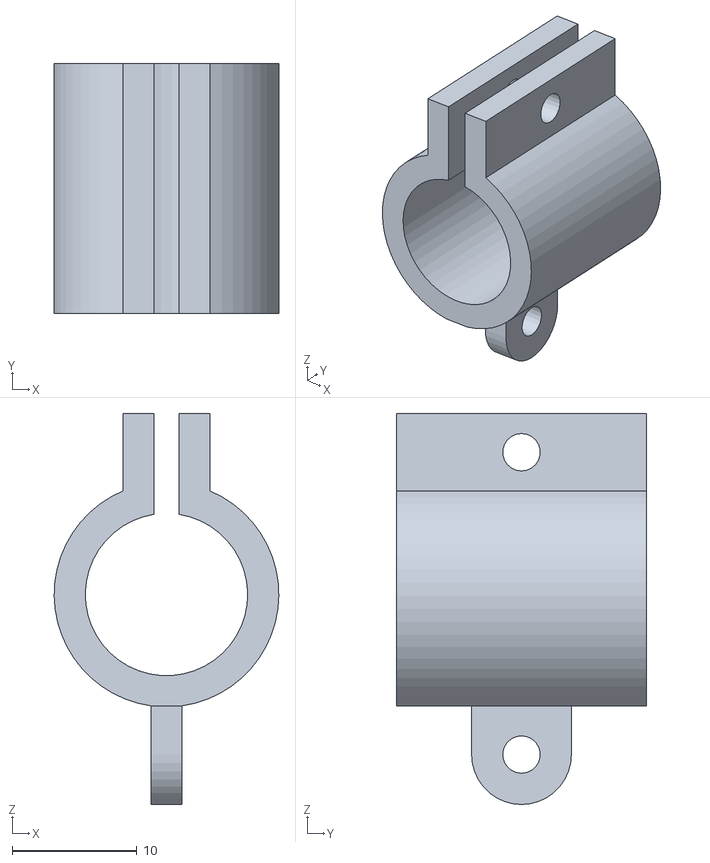
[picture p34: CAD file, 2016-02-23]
3D/sensor_mount_grip.stl
18.0 x 20.0 x 31.3

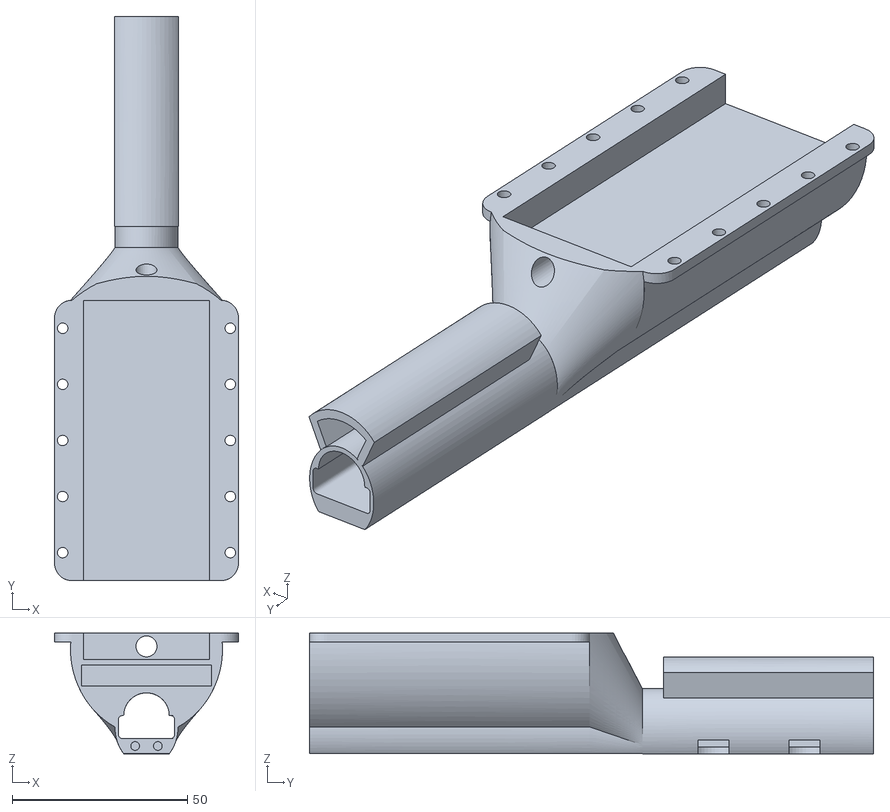
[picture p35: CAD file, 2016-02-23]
3D/enclosure_top.stl
52.5 x 161.0 x 34.4

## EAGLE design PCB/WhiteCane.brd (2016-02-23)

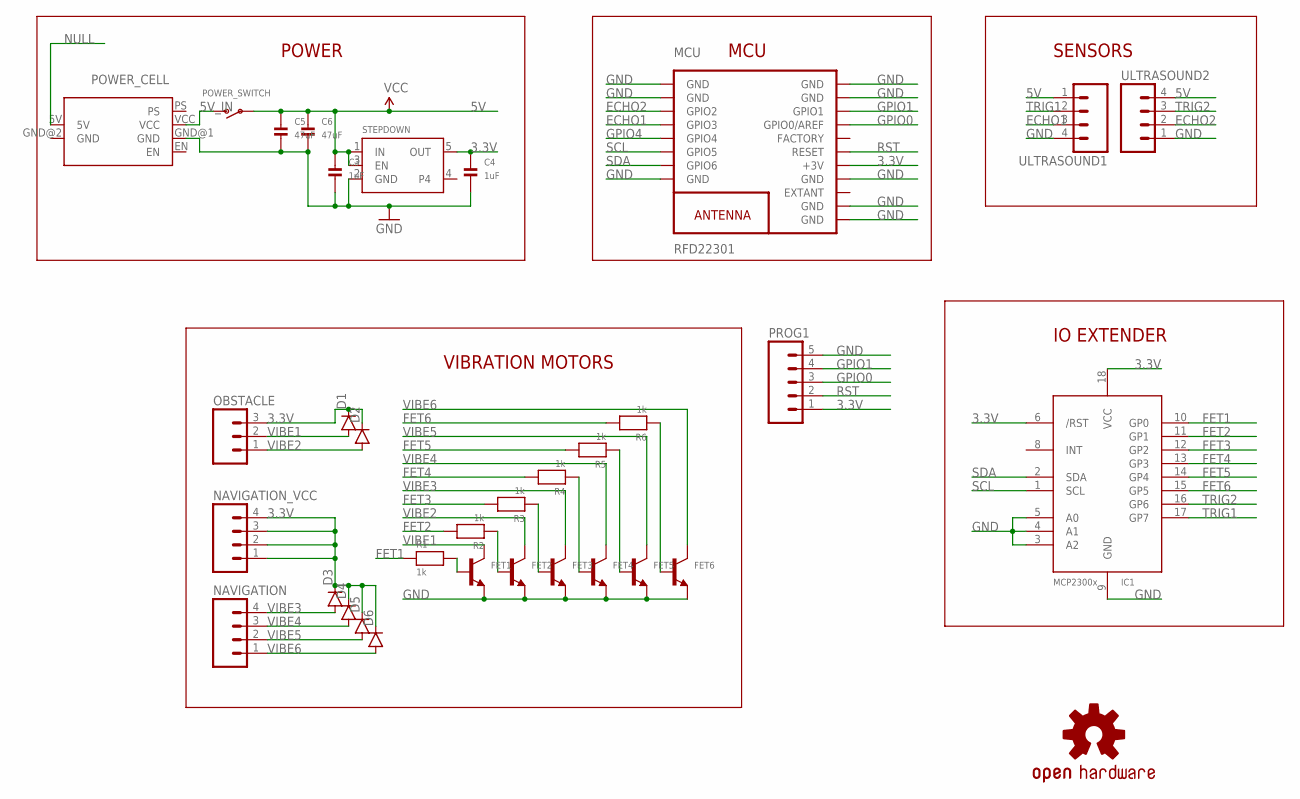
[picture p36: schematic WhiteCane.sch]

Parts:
C3, C4: 1uF; 0603
C5, C6: 47uF; 0805
D1, D2, D3, D4, D5, D6: DIODESOD123; SOD-123
FET1, FET2, FET3, FET4, FET5, FET6: TRANSISTOR_NPN; SOT23-R
IC1: MCP23008/SO; SO18W
LOGO1: OSHW-LOGOL-COPPER; OSHW-LOGO-L_COPPER
MCU: RFD22301
NAVIGATION: M04PTH; 1X04
NAVIGATION_VCC: M04PTH; 1X04
OBSTACLE: M03PTH; 1X03
POWER_CELL: POWER_CELL
POWER_SWITCH: SWITCH_SPST; SPST_SMT_19192
PROG1: M05PTH; 1X05
R1, R2, R3, R4, R5, R6: 1k; 0603
STEPDOWN: VREG_SOT23-5; SOT23-5
ULTRASOUND1, ULTRASOUND2: M04PTH; 1X04

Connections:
3.3V: C4.1, D1.C, D2.C, D3.C, D4.C, D5.C, D6.C, IC1.6 (/RST), IC1.18 (VCC), MCU.13 (+3V), NAVIGATION_VCC.1, NAVIGATION_VCC.2, NAVIGATION_VCC.3, NAVIGATION_VCC.4, OBSTACLE.3, PROG1.1, STEPDOWN.5 (OUT)
5V: C3.1, C5.1, C6.1, POWER_SWITCH.B, STEPDOWN.1 (IN), STEPDOWN.3 (EN), ULTRASOUND1.1, ULTRASOUND2.4
5V_IN: POWER_CELL.VCC, POWER_SWITCH.C (S)
ECHO1: MCU.4 (GPIO3), ULTRASOUND1.3
ECHO2: MCU.3 (GPIO2), ULTRASOUND2.2
FET1: IC1.10 (GP0), R1.1
FET2: IC1.11 (GP1), R2.2
FET3: IC1.12 (GP2), R3.2
FET4: IC1.13 (GP3), R4.2
FET5: IC1.14 (GP4), R5.2
FET6: IC1.15 (GP5), R6.2
GND: C3.2, C4.2, C5.2, C6.2, FET1.2 (E), FET2.2 (E), FET3.2 (E), FET4.2 (E), FET5.2 (E), FET6.2 (E), IC1.3 (A2), IC1.4 (A1), IC1.5 (A0), IC1.9 (GND), MCU.1 (GND), MCU.2 (GND), MCU.8 (GND), MCU.9 (GND), MCU.10 (GND), MCU.12 (GND), MCU.18 (GND), MCU.19 (GND), POWER_CELL.GND@1 (GND), POWER_CELL.GND@2 (GND), PROG1.5, STEPDOWN.2 (GND), ULTRASOUND1.4, ULTRASOUND2.1
GPIO0: MCU.16 (GPIO0/AREF), PROG1.3
GPIO1: MCU.17 (GPIO1), PROG1.4
GPIO4: MCU.5 (GPIO4)
unnamed: FET1.1 (B), R1.2
unnamed: FET2.1 (B), R2.1
unnamed: FET3.1 (B), R3.1
unnamed: FET4.1 (B), R4.1
unnamed: FET5.1 (B), R5.1
unnamed: FET6.1 (B), R6.1
NULL: POWER_CELL.5V
RST: MCU.14 (RESET), PROG1.2
SCL: IC1.1 (SCL), MCU.6 (GPIO5)
SDA: IC1.2 (SDA), MCU.7 (GPIO6)
TRIG1: IC1.17 (GP7), ULTRASOUND1.2
TRIG2: IC1.16 (GP6), ULTRASOUND2.3
VIBE1: D1.A, FET1.3 (C), OBSTACLE.2
VIBE2: D2.A, FET2.3 (C), OBSTACLE.1
VIBE3: D3.A, FET3.3 (C), NAVIGATION.4
VIBE4: D4.A, FET4.3 (C), NAVIGATION.3
VIBE5: D5.A, FET5.3 (C), NAVIGATION.2
VIBE6: D6.A, FET6.3 (C), NAVIGATION.1

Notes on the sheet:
VIBRATION MOTORS
POWER
SENSORS
IO EXTENDER
MCU

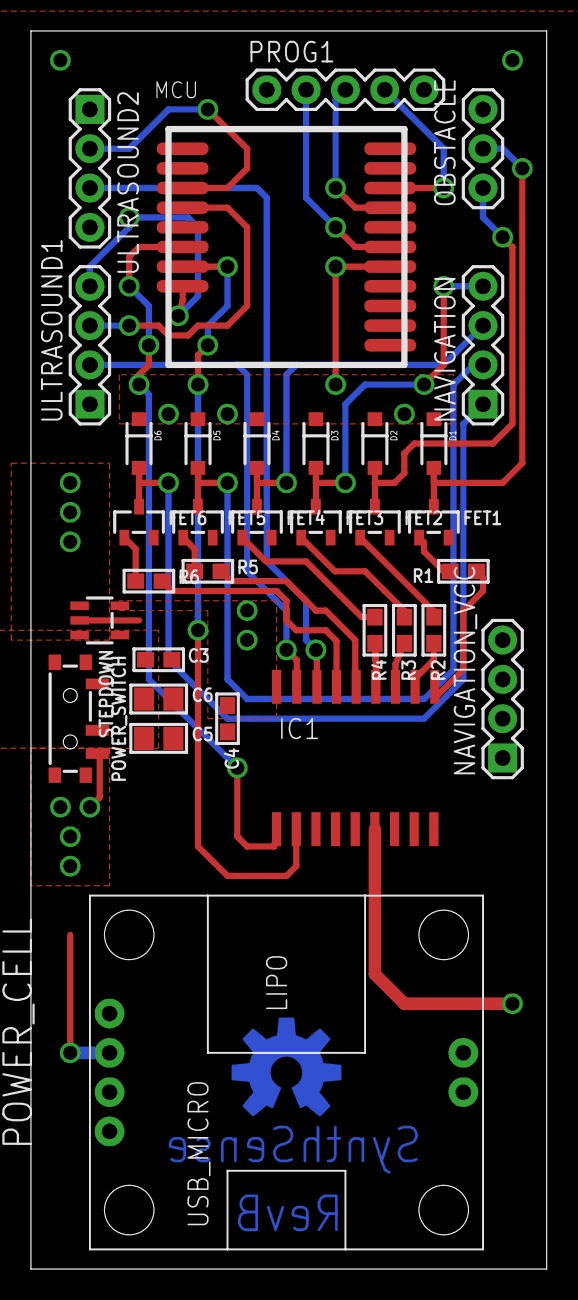
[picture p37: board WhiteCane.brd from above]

Board: 2 copper layers, 33.3 x 80.0 mm, 34 parts (0 on the bottom side), 31 nets.

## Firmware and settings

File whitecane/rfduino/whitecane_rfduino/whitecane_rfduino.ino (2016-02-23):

// Project: Whitecane
// Organization: Synthsense
// Authors: Adhitya Murali, Tomas Vega, Craig Hiller

#include <Wire.h>
#include "Adafruit_MCP23008.h"
#include <RFduinoBLE.h>

#define TRIGGER_PIN_1  7  // I/O extender ID
#define ECHO_PIN_1     3  // RFduino
#define TRIGGER_PIN_2  6  // I/O extender ID
#define ECHO_PIN_2     2  // RFduino

// These should be using the MCP23008 port expander
#define CANE_MOTOR_1        0
#define CANE_MOTOR_2        1
#define NAV_MOTOR_1         2
#define NAV_MOTOR_2         3
#define NAV_MOTOR_3         4
#define NAV_MOTOR_4         5

#define MAX_DISTANCE 500 // Maximum distance we want to ping for (in centimeters). Maximum sensor distance is rated at 400-500cm.

enum state_type {
  INIT,
  US_1,
  VIBRATE_1,
  US_2,
  VIBRATE_2,
};

Adafruit_MCP23008 mcp;
long threshold;
state_type state;
long curr_dist;
int hcsr_timeout;
int inter_ping_delay;
int vibration_delay;
int num_end_rotations;

void pin_set(char pattern) {
  for(char i = 0; i < 8; i++) {
    bool val = (pattern & (1 << i)) >> i;

    if (val == 0) {
      mcp.digitalWrite(i, LOW);
    } else {
      mcp.digitalWrite(i, HIGH);
    }

  }
  
}

long read_distance(int trigger_pin, int echo_pin) {
  mcp.digitalWrite(trigger_pin, LOW);
  delayMicroseconds(2);
  mcp.digitalWrite(trigger_pin, HIGH);
  delayMicroseconds(10);
  mcp.digitalWrite(trigger_pin, LOW);
  long duration = pulseIn(echo_pin, HIGH, hcsr_timeout);
  return duration/58.2;
}

void navband_vibrate_left(void) {
  Serial.print("*****NAV-BAND LEFT");
  for (int i = 4; i <= 32; i=i << 1) {
    pin_set(i);
    delay(200);
  }
  pin_set(0);
}

void navband_vibrate_right(void) {
  Serial.println("*****NAV-BAND RIGHT");
  for (int i = 32; i >= 4; i=i >> 1) {
    pin_set(i);
    delay(200);
  }
  pin_set(0);
}

void navband_vibrate_left_arrive(void) {
  Serial.print("*****NAV-BAND FINAL LEFT");
  navband_vibrate_left();
  for (int i = 0; i < num_end_rotations; i++) {
    pin_set(0);
    delay(100);
    pin_set(32);
    delay(100);
    pin_set(0);
  }
}

void navband_vibrate_right_arrive(void) {
  Serial.print("*****NAV-BAND FINAL RIGHT");
  navband_vibrate_right();
  for (int i = 0; i < num_end_rotations; i++) {
    pin_set(0);
    delay(100);
    pin_set(4);
    delay(100);
    pin_set(0);
  }
}

void navband_vibrate(void) {
  mcp.digitalWrite(NAV_MOTOR_1, HIGH);
  mcp.digitalWrite(NAV_MOTOR_2, LOW);
  mcp.digitalWrite(NAV_MOTOR_3, LOW);
  mcp.digitalWrite(NAV_MOTOR_4, LOW);
  delay(200);

  mcp.digitalWrite(NAV_MOTOR_1, LOW);
  mcp.digitalWrite(NAV_MOTOR_2, HIGH);
  mcp.digitalWrite(NAV_MOTOR_3, LOW);
  mcp.digitalWrite(NAV_MOTOR_4, LOW);
  delay(200);
  
  mcp.digitalWrite(NAV_MOTOR_1, LOW);
  mcp.digitalWrite(NAV_MOTOR_2, LOW);
  mcp.digitalWrite(NAV_MOTOR_3, HIGH);
  mcp.digitalWrite(NAV_MOTOR_4, LOW);
  delay(200);
  
  mcp.digitalWrite(NAV_MOTOR_1, LOW);
  mcp.digitalWrite(NAV_MOTOR_2, LOW);
  mcp.digitalWrite(NAV_MOTOR_3, LOW);
  mcp.digitalWrite(NAV_MOTOR_4, HIGH);
  delay(200);
}

void setup() {
  Serial.begin(9600); // Open serial monitor at 115200 baud to see ping results.
  state = INIT;  // By right this should be CALIBRATION

  // Initialize ultrasonic sensors
  threshold = 100.0; // This is in centimeters!
  hcsr_timeout = 1000;
  inter_ping_delay = 100;
  vibration_delay = 500;
  num_end_rotations = 4;
  pinMode(ECHO_PIN_1, INPUT);
  pinMode(ECHO_PIN_2, INPUT);

  // Initialize Adafruit MCP23008 I/O expander
  mcp.begin();
  for (int i = 0; i < 8; i++) {
    mcp.pinMode(i, OUTPUT);  
  }

  RFduinoBLE.advertisementData = "CouDow";
  RFduinoBLE.deviceName = "ChillerNavBand";
  RFduinoBLE.begin();
}

void loop() {
  switch(state) {

    case INIT:
      state = US_1;
      break;

    case US_1:
      delay(inter_ping_delay); // Wait for some time between pings (about 20 pings/sec). 29ms should be the shortest delay between pings.
      curr_dist = read_distance(TRIGGER_PIN_1, ECHO_PIN_1);
      Serial.print("US_1: ");
      Serial.print(curr_dist);
      Serial.println("cm");
      if ((curr_dist > threshold) || (curr_dist <= 1.0)) {
        state = US_2;
      } else {
        state = VIBRATE_1;
      }
      break;

    case VIBRATE_1:
      Serial.println("VIBRATE 1");
      mcp.digitalWrite(CANE_MOTOR_1, HIGH);
      delay(vibration_delay);
      mcp.digitalWrite(CANE_MOTOR_1, LOW);
      state = US_2;
      break;

    case US_2:
      delay(inter_ping_delay); // Wait for some time between pings (about 20 pings/sec). 29ms should be the shortest delay between pings.
      curr_dist = read_distance(TRIGGER_PIN_2, ECHO_PIN_2);
      Serial.print("US_2: ");
      Serial.print(curr_dist);
      Serial.println("cm");
      if ((curr_dist > threshold) || (curr_dist <= 1.0)) {
        state = INIT;
      } else {
        state = VIBRATE_2;
      }
      break;

    case VIBRATE_2:
      Serial.println("VIBRATE 2");
      mcp.digitalWrite(CANE_MOTOR_2, HIGH);
      delay(vibration_delay);
      mcp.digitalWrite(CANE_MOTOR_2, LOW);
      state = INIT;
      break;
      
    default:
      Serial.print("DEFAULT");
      break;
  }
}

void RFduinoBLE_onReceive(char *data, int len) {
  int cmd = data[0];
  if (cmd == 0){
    navband_vibrate_left();
  } else if (cmd == 1) {
    navband_vibrate_right();
  } else if (cmd == 2) {
    navband_vibrate_left_arrive();
  } else if (cmd == 3) {
    navband_vibrate_right_arrive();
  } else if (cmd == 4) {
    threshold = 50;
  } else if (cmd == 5) {
    threshold = 100;
  } else if (cmd == 6) {
    threshold = 150;
  } else if (cmd == 7) {
    threshold = 200;
  } else if (cmd == 8) {
    threshold = 250;
  }
}

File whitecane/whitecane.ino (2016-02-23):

// Project: Whitecane
// Organization: Synthsense
// Authors: Adhitya Murali, Tomas Vega
// Purpose: Example NewPing library sketch that does a ping about 20 times per second.

#include <NewPing.h>

#define TRIGGER_PIN_1  11  // Arduino pin tied to trigger pin on the ultrasonic sensor.
#define ECHO_PIN_1     10  // Arduino pin tied to echo pin on the ultrasonic sensor.
#define TRIGGER_PIN_2  9
#define ECHO_PIN_2     8
#define MOTOR_1        15
#define MOTOR_2        14
#define MAX_DISTANCE 500 // Maximum distance we want to ping for (in centimeters). Maximum sensor distance is rated at 400-500cm.

NewPing sonar_1(TRIGGER_PIN_1, ECHO_PIN_1, MAX_DISTANCE); // NewPing setup of pins and maximum distance.
NewPing sonar_2(TRIGGER_PIN_2, ECHO_PIN_2, MAX_DISTANCE); // NewPing setup of pins and maximum distance.

unsigned int threshold_us1;
unsigned int threshold_us2;
unsigned int curr_us1;
unsigned int curr_us2;
unsigned int curr_dist;
unsigned int total;

enum state_type {
  INIT,
  US_1,
  VIBRATE_1,
  US_2,
  VIBRATE_2,
};

state_type state;

void setup() {
  Serial.begin(115200); // Open serial monitor at 115200 baud to see ping results.
  state = US_1;  // By right this should be CALIBRATION
  threshold_us1 = 100; // This is in centimeters!
  threshold_us2 = 100; // This is in centimeters!  
  pinMode(MOTOR_1, OUTPUT);
  pinMode(MOTOR_2, OUTPUT);
  total = 0;
}

void loop() {
  switch(state) {
    case INIT:
      state = US_1;
      break;

    case US_1:
      delay(50); // Wait 50ms between pings (about 20 pings/sec). 29ms should be the shortest delay between pings.
      curr_us1 = sonar_1.ping(); // Send ping, get ping time in microseconds (uS).
      curr_dist = curr_us1  / US_ROUNDTRIP_CM;
      Serial.print("US_1: ");
      Serial.print(curr_dist); // Convert ping time to distance in cm and print result (0 = outside set distance range)
      Serial.println("cm");
      if ((curr_dist > threshold_us1) || (curr_dist <= 1.0)) {
        state = US_2;
      } else {
        Serial.println("OBSTACLE DETECTED 1");
        state = VIBRATE_1;
      }
      break;

    case VIBRATE_1:
      digitalWrite(MOTOR_1, HIGH);
      delay(500);
      digitalWrite(MOTOR_1, LOW);
      state = US_2;
      break;

    case US_2:
      delay(50);
      curr_us2 = sonar_2.ping(); // Send ping, get ping time in microseconds (uS).
      curr_dist = curr_us2  / US_ROUNDTRIP_CM;
      Serial.print("US_2: ");
      Serial.print(curr_dist); // Convert ping time to distance in cm and print result (0 = outside set distance range)
      Serial.println("cm");
      if ((curr_dist > threshold_us2) || (curr_dist <= 1.0)) {
        state = INIT;
      } else {
        Serial.println("OBSTACLE DETECTED 2");
        state = VIBRATE_2;
      }
      break;

    case VIBRATE_2:
      digitalWrite(MOTOR_2, HIGH);
      delay(500);
      digitalWrite(MOTOR_2, LOW);
      state = INIT;
      break;

    default:
      Serial.print("DEFAULT");
      break;
  }
}

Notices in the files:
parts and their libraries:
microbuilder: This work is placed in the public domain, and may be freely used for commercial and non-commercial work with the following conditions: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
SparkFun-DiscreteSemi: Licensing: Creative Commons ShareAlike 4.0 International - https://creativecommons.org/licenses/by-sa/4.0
